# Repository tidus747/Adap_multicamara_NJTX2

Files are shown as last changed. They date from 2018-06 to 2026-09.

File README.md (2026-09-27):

# NVIDIA Jetson TX2 Multi-Camera System

Multidisciplinary engineering project covering mechanical design, custom electronics, embedded Linux integration, camera-array calibration and disparity estimation.

> Master's Degree Final Project in Industrial Engineering
>
> Author: Iván Rodríguez-Méndez
>
> Supervisor: Fernando Luis Rosa González
>
> Universidad de La Laguna, 2018





## Project overview

The goal of this project was to develop the hardware and software required to operate a multi-camera array around the NVIDIA Jetson TX2.

The work covered the complete engineering chain:

- custom electronic modules
- mechanical design and fabrication
- camera positioning and physical calibration
- Linux kernel and Device Tree configuration
- camera sensor integration
- GStreamer capture workflows
- multi-camera calibration
- disparity estimation

The repository contains the original engineering artifacts, experimental captures and the complete Master's thesis.

## System architecture

```mermaid
flowchart LR
    SCENE[Scene] --> CAM[Camera sensors]
    CAM --> ELEC[Custom camera and bridge electronics]
    ELEC --> JETSON[NVIDIA Jetson TX2]

    MECH[Mechanical camera array] --> CAM
    ADJ[Camera angle adjustment] --> MECH

    JETSON --> KERNEL[Kernel and Device Tree]
    KERNEL --> DRIVER[Camera drivers]
    DRIVER --> GST[GStreamer capture]

    GST --> DATA[Multi-camera datasets]
    DATA --> CAL[Array calibration]
    CAL --> DISP[Disparity estimation]
    DISP --> RESULTS[Experimental results]
```

See [docs/system-architecture.md](docs/system-architecture.md) for the detailed system view.

## Engineering scope

### Mechanical design

The mechanical subsystem includes:

- complete camera array structure
- camera support and positioning
- camera-angle adjustment mechanisms
- physical calibration elements
- FreeCAD design files
- 3D-printing and manufacturing resources

Source material: [Desarrollo_Mecanico](Desarrollo_Mecanico)

### Electronic design

The electronic development includes several prototype and production-oriented modules:

- OV5680 camera modules
- camera bridge modules
- Raspberry Pi camera sensor adapters
- debug modules
- CNC fabrication test boards
- Jetson support hardware

Source material: [Desarrollo_Electronico](Desarrollo_Electronico)

### Embedded software

The Jetson TX2 integration required work below the application layer.

The repository includes:

- Jetson TX2 Device Tree resources
- Device Tree modifications
- IMX219 sensor support
- camera driver modifications
- kernel compilation scripts
- GStreamer RAW10 patches
- Auvidea J20 configuration
- GPIO setup utilities
- camera-array control and calibration scripts

Source material: [Desarrollo_Software](Desarrollo_Software)

### Computer vision and validation

The completed system was used to acquire multi-camera image sets and validate the full integration through calibration and disparity-estimation experiments.

Experimental data: [Array_captures](Array_captures)

## Engineering case study

A condensed explanation of the problem, system integration and validation strategy is available in:

[docs/engineering-case-study.md](docs/engineering-case-study.md)

The original Master's thesis is preserved in:

[Documentos/tfm_ivan_comp.pdf](Documentos/tfm_ivan_comp.pdf)

## Developed system

<p align="center">
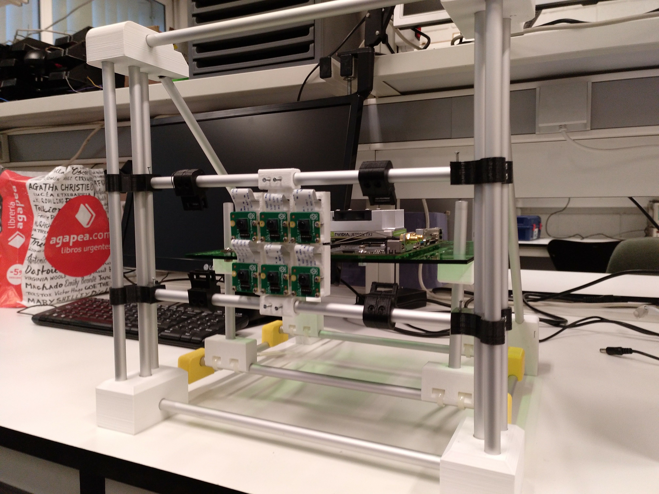
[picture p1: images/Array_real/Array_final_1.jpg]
  
</p>

<p align="center">
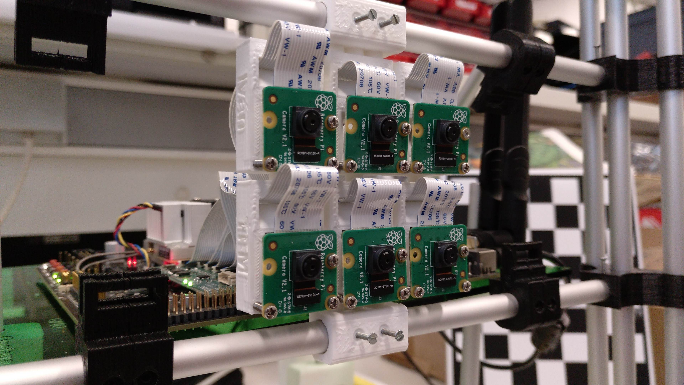
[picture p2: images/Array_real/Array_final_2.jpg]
  
</p>

## Mechanical design

<p align="center">
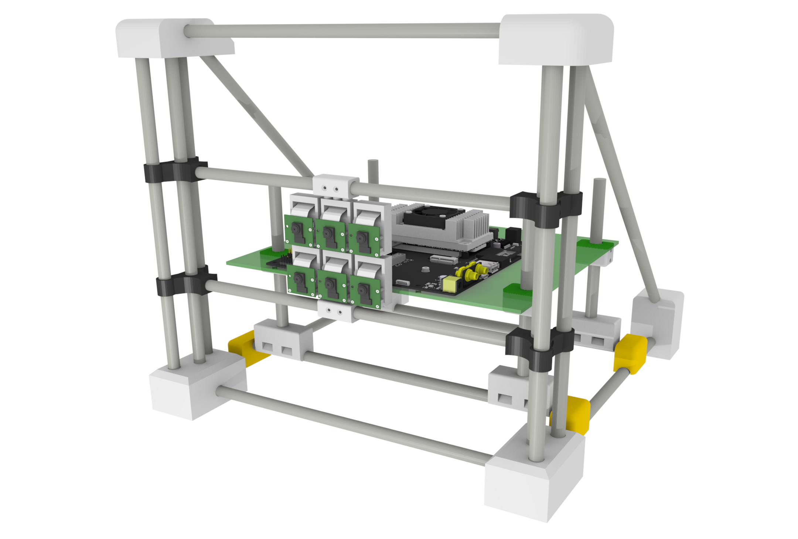
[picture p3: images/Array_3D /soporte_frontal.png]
  
</p>

<p align="center">
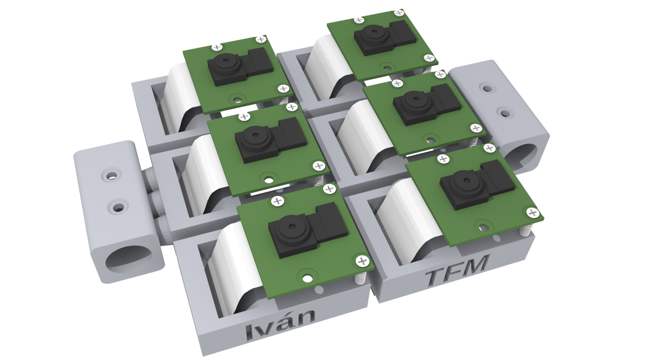
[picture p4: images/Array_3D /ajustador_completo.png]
  
</p>

## Experimental results

Representative disparity-estimation results obtained with the camera array:

<p align="center">
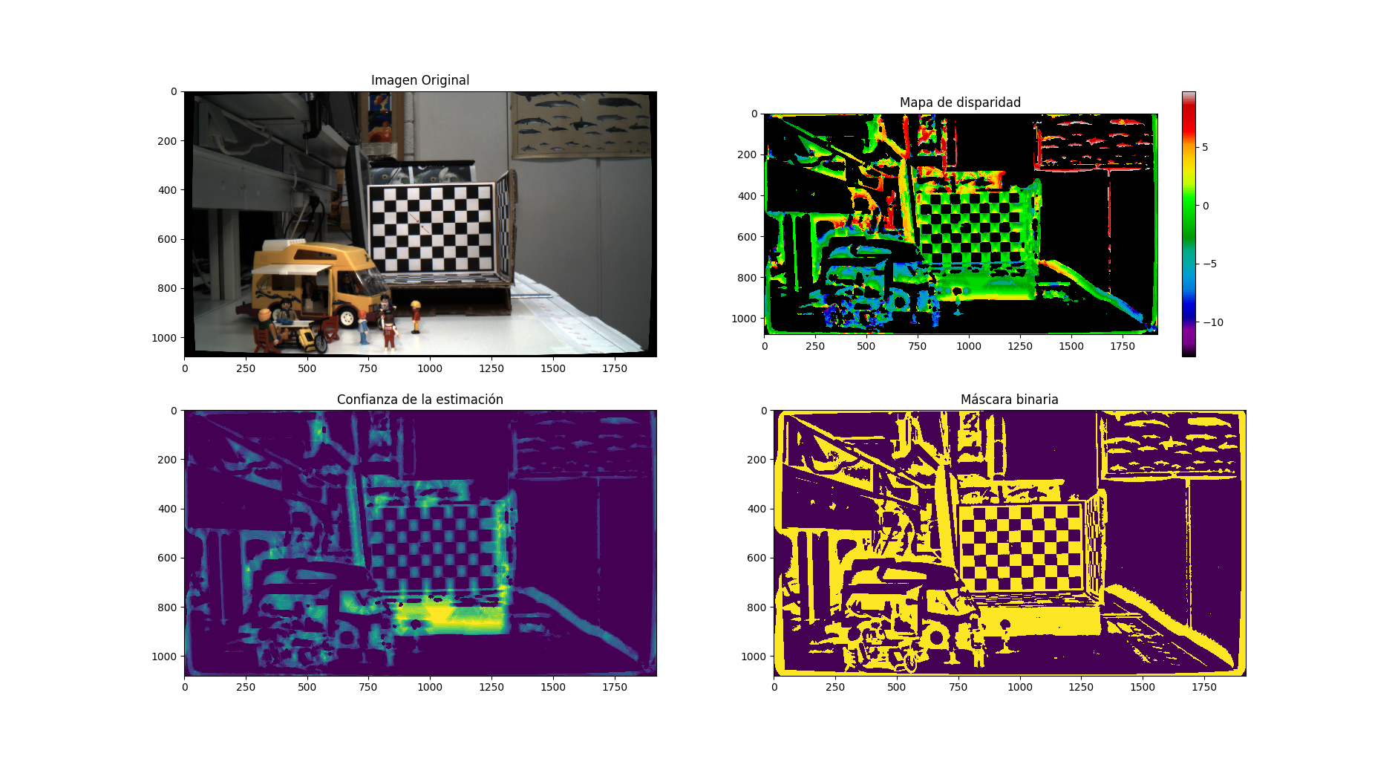
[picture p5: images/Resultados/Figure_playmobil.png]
  
</p>

<p align="center">
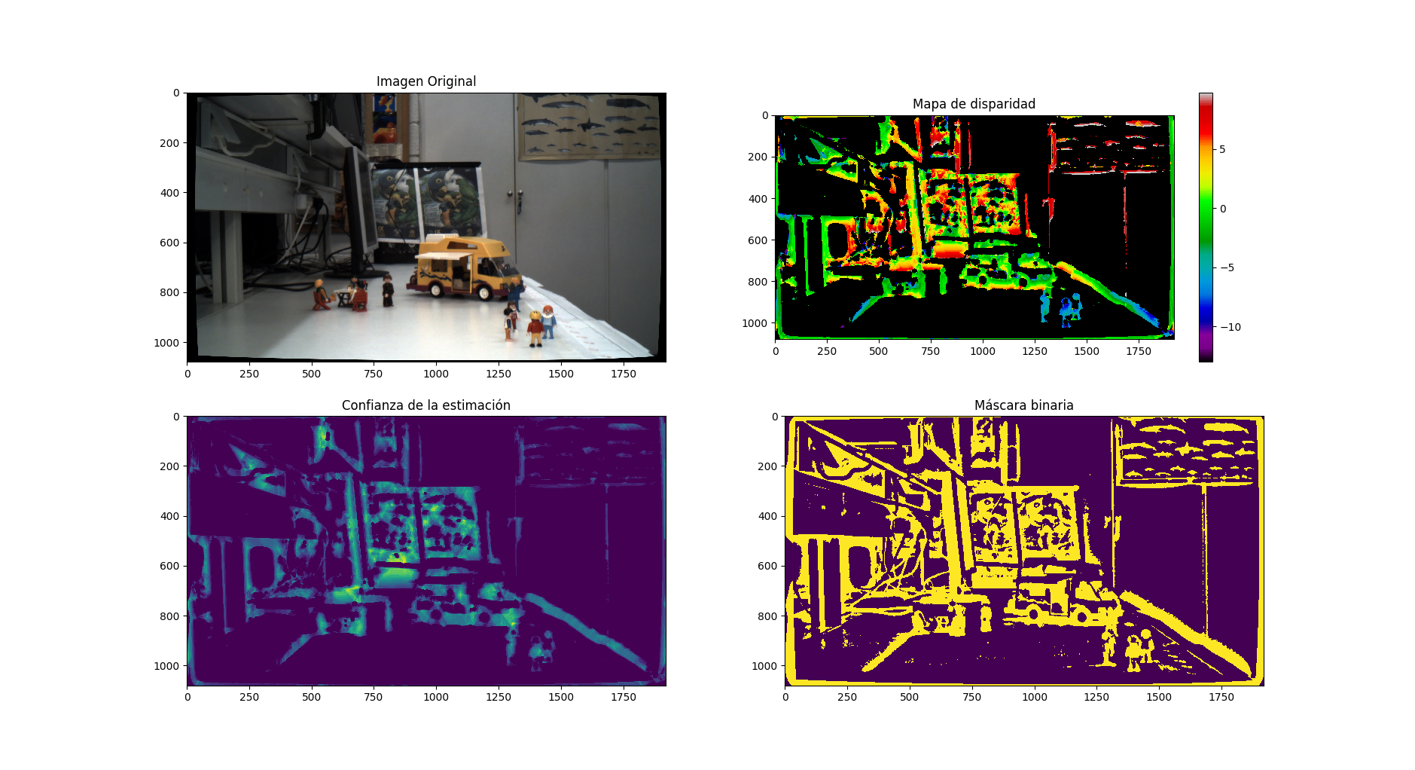
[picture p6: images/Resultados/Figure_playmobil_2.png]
  
</p>

<p align="center">
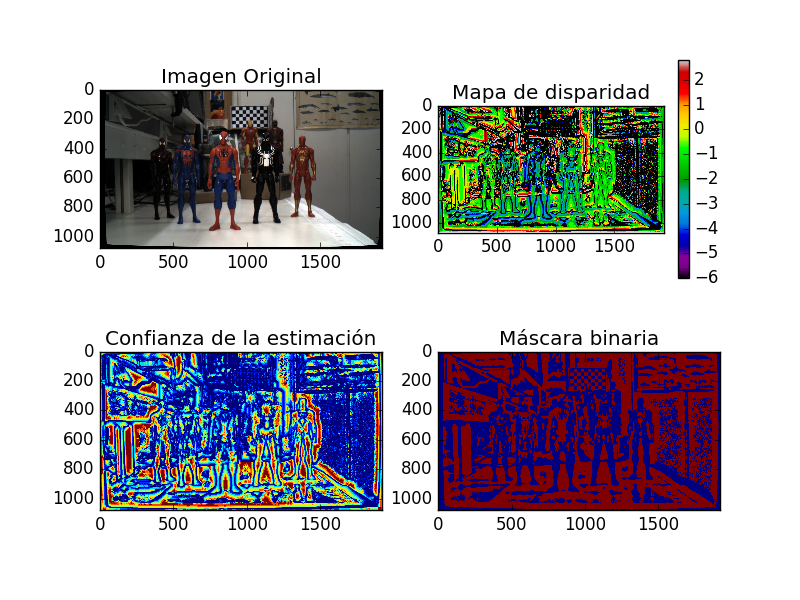
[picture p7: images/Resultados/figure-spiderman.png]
  
</p>

## Repository map

```text
Adap_multicamara_NJTX2/
|-- Array_captures/
|   `-- Experimental multi-camera datasets
|-- Desarrollo_Electronico/
|   `-- Electronic design and fabrication files
|-- Desarrollo_Mecanico/
|   `-- Mechanical design and fabrication files
|-- Desarrollo_Software/
|   `-- Jetson, kernel, drivers, GStreamer and camera scripts
|-- Documentos/
|   `-- Original Master's thesis
|-- docs/
|   |-- engineering-case-study.md
|   `-- system-architecture.md
|-- images/
|   |-- Array_3D /
|   |-- Array_real/
|   |-- Modelo3D_Placas/
|   `-- Resultados/
|-- CONTRIBUTING.md
|-- LICENSE
`-- README.md
```

## Why this project matters

This project is fundamentally an integration project.

The camera system only works when multiple engineering domains work together:

```mermaid
flowchart TD
    SYS[Working multi-camera system]
    ME[Mechanical alignment] --> SYS
    EE[Electronic interfaces] --> SYS
    EMB[Embedded Linux integration] --> SYS
    IMG[Image acquisition] --> SYS
    CAL[Calibration] --> SYS
    CV[Computer vision] --> SYS
```

It required moving repeatedly between physical design, electronics, low-level software, system bring-up and experimental validation.

## Historical note

This project was developed in 2018 using the NVIDIA Jetson TX2 platform and the JetPack/kernel ecosystem available at that time.

The repository is preserved as an engineering record. Kernel patches, Device Tree files, drivers and software instructions should therefore be treated as historical technical material rather than current Jetson setup instructions.

## Development workflow

The original project history is preserved. Future maintenance uses GitFlow without rewriting historical engineering artifacts.

See [CONTRIBUTING.md](CONTRIBUTING.md).

## License

Released under the GNU General Public License v3.0. See [LICENSE](LICENSE).

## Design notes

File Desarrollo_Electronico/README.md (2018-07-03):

# Contenido del directorio

En este directorio se pueden encontrar los diseños de los siguientes módulos:

- [Módulo de cámara para el sensor OV5680](https://github.com/tidus747/Adap_multicamara_NJTX2/tree/master/Desarrollo_Electronico/Modulo_Camara) - Diseño para el módulo de cámara con sensor OV5680.
- [Módulo de cámara para el sensor OV5680 con pistas grandes](https://github.com/tidus747/Adap_multicamara_NJTX2/tree/master/Desarrollo_Electronico/Modulo_Camara_pistas_grandes) - Modificación con pistas más anchas para el módulo de cámara con sensor OV5680.
- [Módulo de depuración](https://github.com/tidus747/Adap_multicamara_NJTX2/tree/master/Desarrollo_Electronico/Modulo_Depuracion) - Diseño para el módulo de depuración de líneas de la Nvidia Jetson TX2.
- [Módulo para pruebas de CNC](https://github.com/tidus747/Adap_multicamara_NJTX2/tree/master/Desarrollo_Electronico/Modulo_pruebas_CNC) - Diseño para el módulo de pruebas de CNC.
- [Módulo para pruebas de CNC versión Tiny](https://github.com/tidus747/Adap_multicamara_NJTX2/tree/master/Desarrollo_Electronico/Modulo_pruebas_CNC_Tiny) - Diseño reducido para el módulo de pruebas de CNC.
- [Módulo puente para módulo de cámara basado en el sensor OV5680](https://github.com/tidus747/Adap_multicamara_NJTX2/tree/master/Desarrollo_Electronico/Modulo_puente) -  Diseño del módulo puente para el módulo de cámara basado en el sensor OV5680.
- [Módulo puente para módulo de cámara basado en el sensor OV5680 con VIAS MOD](https://github.com/tidus747/Adap_multicamara_NJTX2/tree/master/Desarrollo_Electronico/Modulo_puente_VIAS_MOD) - Diseño del módulo puente para el módulo de cámara basado en el sensor OV5680 con VIAS más grandes.
- [Módulo puente para módulo de cámara basado en el sensor OV5647/IMX219](https://github.com/tidus747/Adap_multicamara_NJTX2/tree/master/Desarrollo_Electronico/Modulo_puente_Raspberry_Camera) - Diseño para el módulo puente para los módulos de cámara con sensor OV5647/IMX219.
- [Módulo puente para módulo de cámara basado en el sensor OV5647/IMX219 sin EEPROM](https://github.com/tidus747/Adap_multicamara_NJTX2/tree/master/Desarrollo_Electronico/Modulo_puente_Raspberry_Camera_Dupont_NO_EEPROM) - Diseño para el módulo puente para los módulos de cámara con sensor OV5647/IMX219 sin EEPROM.
- [Diseño para el soporte de la Nvidia Jetson TX2](https://github.com/tidus747/Adap_multicamara_NJTX2/tree/master/Desarrollo_Electronico/Soporte_Jetson) - Diseño para el soporte de la Nvidia Jetson TX2.

# Módulos desarrolados

<p align="center">
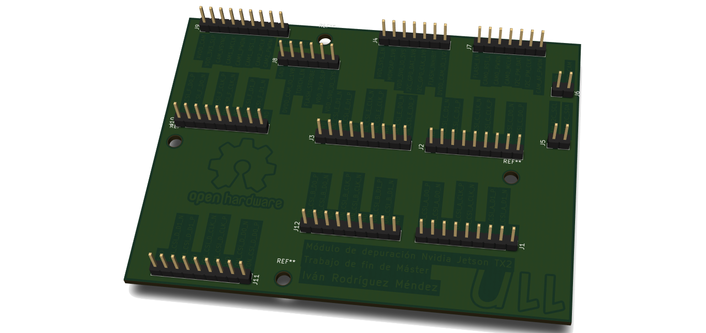
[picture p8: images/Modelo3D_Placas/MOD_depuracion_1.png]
  
</p>

<p align="center">
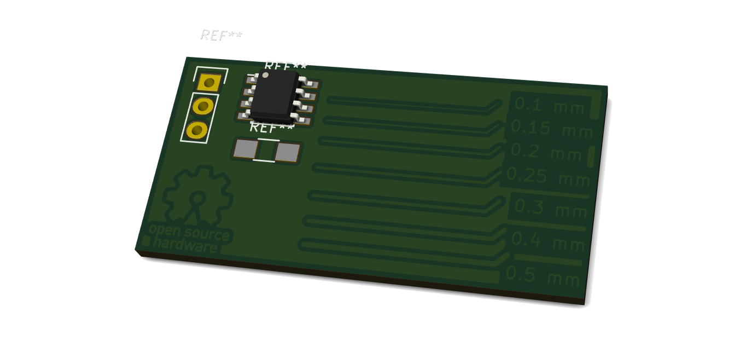
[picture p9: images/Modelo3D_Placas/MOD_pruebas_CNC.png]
  
</p>

<p align="center">
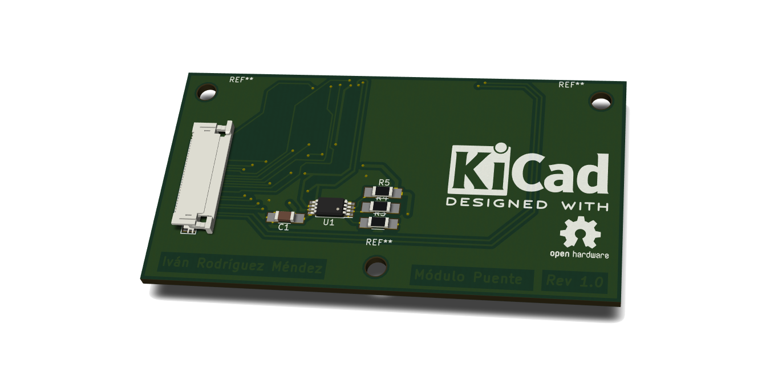
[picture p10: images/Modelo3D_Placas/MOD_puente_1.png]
  
</p>

<p align="center">
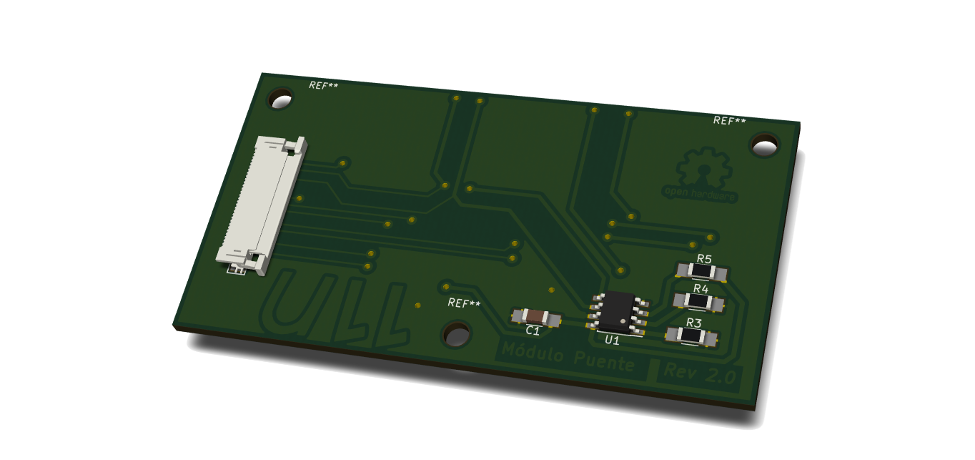
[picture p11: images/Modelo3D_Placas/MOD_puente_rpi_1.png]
  
</p>

<p align="center">
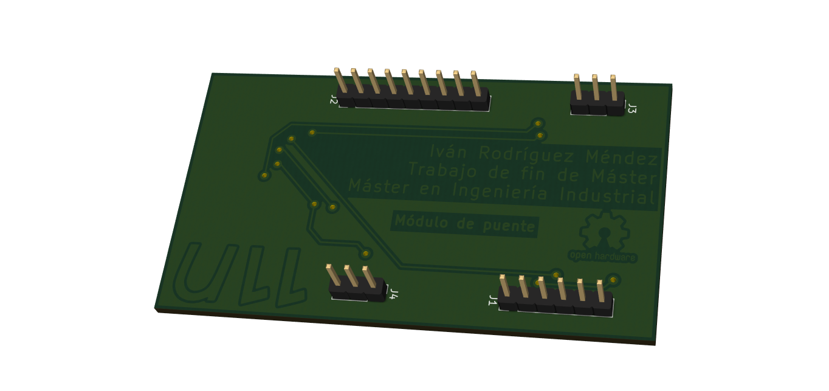
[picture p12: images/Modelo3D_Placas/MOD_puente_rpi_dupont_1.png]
  
</p>

<p align="center">
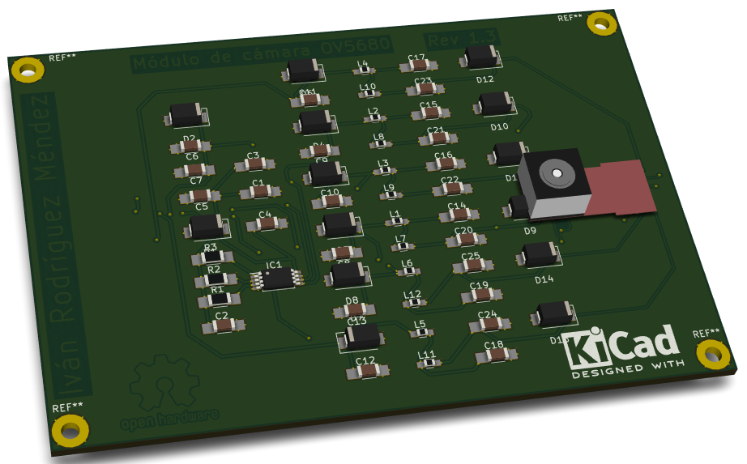
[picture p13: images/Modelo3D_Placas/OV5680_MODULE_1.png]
  
</p>

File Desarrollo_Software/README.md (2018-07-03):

# Contenido del directorio

En este directorio pueden encontrarse los siguientes los siguientes desarrollos realizados y recursos:

- [*Scripts* Array de cámaras](https://github.com/tidus747/Adap_multicamara_NJTX2/tree/master/Desarrollo_Software/Camera_array) - *Scripts* para el control y la calibración del *array* de cámaras.
- [*Device Tree Binary* Originales de la NJTX2](https://github.com/tidus747/Adap_multicamara_NJTX2/tree/master/Desarrollo_Software/Jetson_TX2_original_DTB) - Ficheros originales para los *Device Tree Binary* de la Nvidia Jetson TX2 en su versión del *Jetpack 28.2*.
- [Código fuente módulos de cámara PDF](https://github.com/tidus747/Adap_multicamara_NJTX2/tree/master/Desarrollo_Software/PDF_Code_Cameras) - PDFs con los códigos fuente de los módulos de cámara utilizados.
- [Parches para el *device tree* para el sensor IMX219](https://github.com/tidus747/Adap_multicamara_NJTX2/tree/master/Desarrollo_Software/Patches_DT_IMX219) - Parches para el *device tree* para permitir la utilización de un módulo de cámara con el sensor IMX219.
- [Parches para *GStreamer*](https://github.com/tidus747/Adap_multicamara_NJTX2/tree/master/Desarrollo_Software/Patches_Gstreamer_RAW10) - *Scripts* para aplicar los parches de *Gstreamer* en la Nvidia Jetson TX2. Estos parches permiten el uso de capturas de imágenes *raw* de 10 bits.
- [Parches para el uso de sensores de Raspberry Pi](https://github.com/tidus747/Adap_multicamara_NJTX2/tree/master/Desarrollo_Software/Patches_IMX219) - *Scripts* para el uso de sensores de Raspberry Pi en la Nvidia Jetson TX2.
- [*Scripts* para la compilación del *Kernel* de la NJTX2](https://github.com/tidus747/Adap_multicamara_NJTX2/tree/master/Desarrollo_Software/Scripts_Jetson) - *Scripts* para la compilación del *kernel* de la Nvidia Jetson TX2.
- [*Scripts* para la configuración del Auvidia J20](https://github.com/tidus747/Adap_multicamara_NJTX2/tree/master/Desarrollo_Software/Setup_Auvidea_J20) - *Scripts* para la configuración del Auvidea J20 y los GPIO.

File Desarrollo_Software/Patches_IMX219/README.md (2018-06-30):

# Conexión de la cámara de Raspberry Pi (Sensor IMX219, V2.1) con Nvidia Jetson TX2

## Introducción

En esta guía explicaremos todos los pasos seguidos para la correcta generación de los ficheros necesarios en la conexión del **sensor IMX219**. Para este propósito en primer lugar, definiremos los pasos a seguir en el desarrollo para la implementación de los módulos de cámra. Todos los recursos que hemos utilizado para el desarrollo de esta guía, se encuentran al final de la misma.

## Preparación de elementos necesarios (Hardware/Software)

Antes de comenzar con el desarrollo es necesario contar con una serie de elementos básicos tanto de software como de hardware. Comenzaremos con los elementos de hardware necesarios y continuaremos enumerando los elementos de software.

### Hardware

Lo primero que necesitaremos será el kit de desarrollo de [Nvidia Jetson TX2](https://www.nvidia.es/autonomous-machines/embedded-systems-dev-kits-modules/). Por otro lado, necesitaremos un dispositivo que nos permita conectar las cámaras a la Jetson TX2, en nuestro caso hemos optado por el conector [J20 de Auvidea](https://auvidea.com/j20/). Por último, necesitaremos los módulos de cámara que implementaremos en nuestra placa. En este caso tenemos dos opciones si hablamos de módulos compatibles con Raspberry Pi. Podemos optar por la [versión 2.1](https://www.raspberrypi.org/products/camera-module-v2/) o por la [versión 1.3](https://uk.pi-supply.com/products/raspberry-pi-camera-board-v1-3-5mp-1080p). Optaremos por implementar la versión más actualizada de este sensor, esta es la versión 2.1.

- Sensor OV5647 (Versión 1.3 de cámara Rpi)

<p align="center">
  
</p>
     
- Sensor IMX219 (Version 2.1 de cámara Rpi)

<p align="center">
  
</p>

### Software

Con respecto al software necesario para la implementación de esta herramienta, necesitaremos lo siguiente:

- [Ubuntu 16.04 LTS](http://releases.ubuntu.com/16.04/), para la programación y la carga del nuevo kernel en la NVDIA Jetson (tanto para la TX1 como para la TX2) es necesario contar con este sistema operativo. Esto es así debido a que el SDK desarrollado por NVIDIA para la carga del código está especificamente desarrollado para este sistema.
- [SDK Jetson TX1/TX2](https://developer.nvidia.com/embedded/jetpack), el NVIDIA Jetpack nos proporciona las herramientas necesarias para la descarga y la modificación del código fuente de las NVIDIA Jetson. Por otro lado, también instalará en nuestro sistema herramientas como TensorFlow o ejemplos para la renderización con CUDA que posteriormente podrías ser implementados en el kit de desarrollo.
- [Linaro ToolChain](http://releases.linaro.org/components/toolchain/binaries/5.3-2016.02/), esta herramienta nos servirá para compilar el kernel de la NVIDIA Jetson en nuestro sistema y posteriormente cargarlo en la placa.

## Implementación del sensor a nivel de Software

Antes de comenzar, debemos determinar cuales son los pasos que debemos ejecutar para la correcta implementación del código en la plataforma:

1. Preparar los ficheros fuente del *Device Tree*
2. Modificar los archivos del *Device Tree* correctamente.
3. Modificar los ficheros fuente del módulo de cámara. 
4. Configurar el Kernel para detectar los módulos qe hemos añadido.
5. Compilar el kernel.
6. Cargar el kernel en la NVIDIA Jetson TX2.
7. Cargar los **DTB** en la Jetson TX2.
8. Testear el correcto funcionamiento del sistema.

Una vez hemos definido los pasos a seguir, podemos introducir cada uno de ellos con un mayor nivel de detalle.

### Preparación de ficheros fuente del *Device Tree* 

En general, en los sistemas Linux, existen dos formas de modificar el kernel. Los dos métodos son los siguientes:

- Mediante el **Archivo de configuración del kernel**: esto le indicará al kernel qué características y controladores deberían compilarse. También puede especificar qué controladores deben empaquetarse en el kernel y cuáles deben compilarse pero separarse del kernel. En nuestro caso, modificaremos esto para decirle al kernel que cree compatibilidad con el controlador IMX219.

- Mediante el **Device Tree Source (DTS)**: así es como puede configurar el núcleo en el arranque para que se comporte de manera diferente en una placa frente a otra. Un claro ejemplo lo podmeos encontrar con la Raspberry Pi y la Raspberry Pi Zero. Estas dos placas son muy diferentes a simple vista pero tienen el mismo kernel porque hay dos archivos DTS diferentes para él.

Como hemos comentado, necesitamos agregar soporte para la cámara IMX219 (Cámara Raspberry Pi Modelo 2.1). Debido a que no existe un mecanismo para reconocer las cámaras CSI mientras el kernel se está ejecutando, tenemos que modificar el **DTS** para decirle al kernel cómo reconocerlas. Esto es muy diferente con respecto al funcionamiento de un USB, por ejemplo, porque en el caso del USB existe un mecanismo estándar que el kernel puede usar para reconocer cuando se inserta un nuevo dispositivo, para el CSI esto no es así. Por lo tanto, cada placa está configurada con un archivo interno conocido como **DTB (Device Tree Binary)**. Este **DTB** es una versión compilada de los archivos **DTS (Device Tree Source)** y **DTSi (Device Tree Source Include)**.

Necesitamos configurar el archivo DTS para reconocer la cámara IMX219, para hacer esto tenemos que describir lo siguiente:

- A qué puertos CSI están conectadas las cámaras.
- Cómo se deben configurar las cámaras usando I2C.
- Qué modos de visualización tienen las cámaras (¿Tiene 1920x1080 y / o 1280x720).
- Cómo configurar la arquitectura de entrada de video del TX2.

Todo esto debe recogerse en un fichero **DTS**. Podemos este fichero desde cero, pero para la gran mayoría de casos puede usarse el archivo **DTS** predeterminado utilizado para los kits de desarollo de NVIDIA. En el caso de que se quiera obtener un mayor control sobre este procedimiento puede consultarse el siguiente [enlace](https://cospandesign.github.io/linux/2017/10/27/tx2-bringup.html). En nuestro caso, optaremos por crear nuestro fichero **DTS** partiendo de los códigos creados por NVIDIA. La ruta predefinida para localizar el fichero de configuración predeterminado en la Jetson TX2 es:

```
Linux_for_Tegra/sources/hardware/nvidia/platform/t18x/quill/kernel-dts/tegra186-quill-p3310-1000-c03-00-base.dts
```
En la ruta anterior podemos encontrar algo de información aunque realmente, gran parte de la configuración se encuentra en esta otra ruta:

```
Linux_for_Tegra/sources/hardware/nvidia/platform/t18x/quill/kernel-dts/tegra186-quill-p3310-1000-a00-00-base.dts
```

Antes de continuar, es probable que aún no dispongas de los ficheros que hemos mencionado por lo que será necesario descargarlos. En la siguiente sección explicaremos como realizar este proceso correctamente.

### Descarga del NVIDIA JetPack 3.2 y los ficheros fuente del kernel

#### Descarga del NVIDIA JetPack

1. Descarga la versión 3.2 (o su versión más reciente) desde el siguiente [enlace](https://developer.nvidia.com/embedded/dlc/jetpack-l4t-3_2-ga).
2. Mueve los archivos binarios que acabas de descargar a un directorio donde quieras que ocurra la instalación. La ruta recomendada sería `/home/$USER/JetPack-L4T-3.2`. En tal caso, los comandos a introducir en el terminal serían los siguientes:

```
mkdir -p /home/$USER/JetPack-L4T-3.2
mv JetPack-L4T-3.2-linux-x64_b196.run /home/$USER/JetPack-L4T-3.2/
```

3. Marcamos como ejecutable el archivos y le asignamos los permisos.

```
cd /home/$USER/JetPack-L4T-3.2
chmod +x JetPack-L4T-3.2-linux-x64_b196.run
```

4. Instalar el JetPack.

```
./JetPack-L4T-3.2-linux-x64_b196.run
```

5. Sigue las instrucciones para la instalación. Selecciona la placa en el instalador (TX1, TX2, TX2i).

#### Descarga de los ficheros fuente del kernel

Para descargar todos los ficheros necesarios llamaremos `$DEVDIR` al directorio donde se encuentran los ficheros de desarrollo. En el caso de haber usado los comandos indtroducidos anteriormente tendríamos: 

- **Para la TX1**
```
export DEVDIR=$HOME/JetPack-L4T-3.2/64_TX1/Linux_for_Tegra
```
- **Para la TX2**
```
export DEVDIR=$HOME/JetPack-L4T-3.2/64_TX2/Linux_for_Tegra
```

Para descargar todos los ficheros fuente, usaremos el script *source_sync.sh* 

```
cd $DEVDIR/
./source_sync.sh
```

Este comando descargará además el bootloader y el kernel. Cuando el script pregunte por el tag que queremos sincronizar, introducir **tegra-l4t-r28.2** en ambos casos.

### Modificación de ficheros fuente del *Device Tree* 

Una vez hemos descargado los ficheros fuente, modificaremos el fichero disponible en la siguiente ruta:

```
Linux_for_Tegra/sources/hardware/nvidia/platform/t18x/quill/kernel-dts/tegra186-quill-p3310-1000-a00-00-base.dts
```

Para simplificar el desarrollo, se desactivará el soporte inteligente para la administración de cámaras de NVIDIA y se eliminarán las referencias a otros módulos de cámara. El fichero tendría el siguiente aspecto:

```
#include <t18x-common-platforms/tegra186-quill-common-p3310-1000-a00.dtsi>
#include <t18x-common-platforms/tegra186-quill-power-tree-p3310-1000-a00-00.dtsi>
//#include <t18x-common-platforms/tegra186-quill-camera-modules.dtsi>
#include <t18x-common-modules/tegra186-display-e3320-1000-a00.dtsi>

/* comms dtsi file should be included after gpio dtsi file */
#include <t18x-common-platforms/tegra186-quill-comms.dtsi>
#include <t18x-common-plugin-manager/tegra186-quill-p3310-1000-a00-plugin-manager.dtsi>
#include <t18x-common-modules/tegra186-super-module-e2614-p2597-1000-a00.dtsi>
#include <t18x-common-plugin-manager/tegra186-quill-display-plugin-manager.dtsi>
#include <t18x-common-prod/tegra186-priv-quill-p3310-1000-a00-prod.dtsi>
//#include <t18x-common-plugin-manager/tegra186-quill-camera-plugin-manager.dtsi>

#include <dt-bindings/linux/driver-info.h>
```

Ahora que hemos eliminado todas las referencias a las cámaras anteriores, vamos a agregar dos archivos. Uno que configurará la(s) cámara(s) de nivel de la placa y el otro para configurar la arquitectura interna de la Interfaz de video de la Jetson TX2.

Para ello, crearemos un nuevo archivo llamado *tegra186-my-camera-config-a00.dtsi* en el siguiente directorio:
```
Linux_for_Tegra/sources/hardware/nvidia/platform/t18x/common/kernel-dts/t18x-common-platforms/
```
Crearemos un segundo fichero con el mismo nombre en este otro directorio:
```
Linux_for_Tegra/sources/hardware/nvidia/platform/t18x/common/kernel-dts/t18x-common-modules/
```

El fichero *my-camera-config* se puede cambiar a lo que quieras y *a00* es solo la primera versión de este archivo.

Por el momento, usaremos la versión alojada en *platforms* del archivo como paso para el módulo, pero técnicamente se pueden anular los *modules* abstractos previstos para alguna plataforma general.

Dentro de la versión de *platforms* del archivo, incluimos la siguiente línea:
```
#include <t18x-common-modules/tegra186-my-camera-config-a00.dtsi>

```
Dentro del fichero de configuración necesitamos configurar una serie de parámetros para que la cámara sea capaz de funcionar. Los módulos son los siguientes:

* Permitir que los GPIOs de la Jetson TX2 puedan tener las siguientes funcionalidades:
    * Resetear las líneas
    * Posible incorporación de un multiplexor de direcciones I2C
* TX2’s host1x
    * Componente NVCSI: Este componente servirá para configurar las líneas CSI para comunicarse con las cámaras correctamente.
    * Componente VI: Configura la salida del NVCSI de forma directa a las líneas del ISP o directamente sobre la memoria del dispositivo.
    * Componente I2C: Configuración de la salida de la cámara a vídeo.
* GPIOs
    * Configurar los GPIOs para que posean cierto comportamiento como por ejemplo, resetear la cámara, encenderla o apagar sus reguladores.
* *Tegra-camera-platform*
    * Describir la localización física de la cámara.
    * Configurar el ISP para procesar las imágenes.
    * Describir otros elementos que puedan hacer falta a la cámara, como por ejemplo el enfoque.

Para comprender mejor todo lo anterior, se ha ilustrado la idea principal en la siguiente imagen:

<p align="center">
  
</p>

Todas las cámaras de Raspberry Pi tienen la misma dirección I2C, por lo que necesitamos una manera de distinguir una cámara de otra. La manera más fácil es con un multiplexor. Por esta razón, usaremos un multiplexor GPIO ya que el controlador para esta ya está integrado en el kernel.

En alto nivel si observamos la figura anterior, los datos de las cámaras de  Raspberry Pi llegan a la Jetson TX2 a través de los canales CSI representados en azul. Solo necesitamos un bus CSI de dos canales en este caso así que tomamos CSI A, si necesitáramos cuatro canales, reservaríamos dos bloques. El núcleo **NVCSI** extraerá la imagen sin formato del protocolo CSI y enviará los datos a **VI**. Este componente *Video Input* es esencialmente un enrutador de video, enruta el video al ISP o directamente a la memoria del dispositivo. Si la cámara de Raspberry Pi tiene un procesador de señal de imagen interno para convertir la imagen a una imagen RGB útil, le diremos al VI que enrute los datos de imagen a la memoria, pero como la cámara no tiene un ISP, usamos el ISP que posee la Jetson TX2. El proceso de enrutar los datos de video después del componente **VI** se realiza dentro del territorio del usuario cuando el kernel se inicia, por lo que terminamos una vez que el **VI** está conectado correctamente y el usuario ya tiene acceso a los datos.

Una vez comprendido todo esto, descargaremos los siguientes ficheros:

- [module tegra186-my-config-a00.dtsi](http://cospandesign.github.io/assets/files/posts/rpi-camera/tegra186-my-config-camera-a00_MODULE.dtsi)
- [platform tegra186-my-config-a00.dtsi](http://cospandesign.github.io/assets/files/posts/rpi-camera/tegra186-my-config-camera-a00_PLATFORM.dtsi)

Los directorios para guardar estos ficheros serían los siguientes:

```
Linux_for_Tegra/sources/hardware/nvidia/platform/t18x/common/kernel-dts/t18x-common-modules/
```
```
Linux_for_Tegra/sources/hardware/nvidia/platform/t18x/common/kernel-dts/t18x-common-platforms/
```
Por último, es necesario incluir el fichero `tegra186-my-camera-config-a00.dtsi` en la cabecera de nuestro fichero **dts** de configuración base del sistema. En el interior del fichero `tegra186-quill-p3310-1000-c03-00-base.dts` debemos añadir la siguiente línea:

```
#include <t18x-common-platforms/tegra186-my-camera-config-a00.dtsi>
```

Debería tener el siguiente aspecto:

```
#include "tegra186-quill-p3310-1000-a00-00-base.dts"
#include <t18x-common-platforms/tegra186-my-camera-config-a00.dtsi>

/ {
  nvidia,dtsfilename = __FILE__;
  nvidia,dtbbuildtime = __DATE__, __TIME__;
  ...
```

Una vez hecho esto podemos pasar a realizar las modificaciones sobre los módulos de cámara.

### Modificación de ficheros fuente del módulo de cámara

Lamentablemente, el controlador para el sensor **IMX219** suministrado por NVIDIA no es compatible con el módulo de Raspberry Pi. Por lo tanto, es necesario realizar algunas pequeñas modificaciones. Entre otras cosas, los requisitos del regulador deben eliminarse y las tablas de modos deben modificarse. Para realizar dicha modificación simplemente descargue los siguientes archivos:

- [imx219.c](http://cospandesign.github.io/assets/files/posts/rpi-camera/imx219.c)
- [imx219_mode_tbls.h](http://cospandesign.github.io/assets/files/posts/rpi-camera/imx219_mode_tbls.h)

Sobrescribe los ficheros existentes en el siguiente directorio con los descargados anteriormente:

```
Linux_for_Tegra/sources/kernel/kernel-4.4/drivers/media/i2c
```

### Configuración del kernel para detectar los módulos añadidos

Una vez descargado e instalado [toolchain](http://developer.ridgerun.com/wiki/index.php?title=Compiling_Tegra_X1/X2_source_code#Toolchain) podremos preparar el Kernel para su compilación. Durante la preparación, configuraremos los archivos que queremos compilar y entre ellos añadiremos los ficheros que hemos modificado y los módulos que necesitamos para el correcto funcionamiento de las cámaras.

EL primer paso será configurar el entorno que vamos a utilizar, introduciendo los comandos siguientes:

```
mkdir -p $DEVDIR/images/modules 
mkdir -p $DEVDIR/images/packages 
export CROSS_COMPILE=/opt/linaro/gcc-linaro-5.3-2016.02-x86_64_aarch64-linux-gnu/bin/aarch64-linux-gnu-
export CROSS32CC=/opt/linaro/gcc-linaro-5.3-2016.02-x86_64_arm-linux-gnueabihf/bin/arm-linux-gnueabihf-gcc
export KERNEL_MODULES_OUT=$DEVDIR/images/modules
export TEGRA_KERNEL_OUT=$DEVDIR/images
export ARCH=arm64
```

Limpiamos la configuración anterior del kernel:

```
cd $DEVDIR/sources/kernel/kernel-4.4
make mrproper
```

Configuramos el kernel:

```
make O=$TEGRA_KERNEL_OUT tegra18_defconfig
make O=$TEGRA_KERNEL_OUT menuconfig
```

**IMPORTANTE**: Para ejecutar el paso anterior, es posible que necesites instalar los siguientes paquetes si obtienes algún error al ejecutarlo.

```
sudo apt-get install libncurses5 libncurses5-dev
```

Al ejecutar el comando `make O=$TEGRA_KERNEL_OUT menuconfig` nos aparecerá un menú en el que podremos configurar los módulos que queremos cargar para su compilación en el kernel. La ventana que nos aparecerá en nuestro terminal será igual a la que vemos en la siguiente imagen:

<p align="center">
  
</p>

Dentro de este menú debemos buscar un módulo llamado *i2c-gpio-mux*. Para ello pulsaremos `/` para abrir el buscador y posteriormente escribiremos `I2C_MUX_GPIO`, pulsamos **enter** y debería aparecer lo siguiente:

<p align="center">
  
</p>

Presiona la tecla *1* hasta que aparezca un nuevo menú y posteriormente la tecla *y* para que un * aparezca en la selección de la siguiente manera:

<p align="center">
  
</p>

Haremos lo mismo para buscar el módulo de cámara IMX219. Una vez hecho esto, usaremos las flechas de dirección para guardar la configuración. El archivo debe tener el nombre por defecto, es decir, `.config`. Configurado el Kernel podemos pasar a su compilación.

### Compilación del kernel y los DTB

Una vez realizados los pasos anteriores ya podemos compilar el kernel de nuestro sistema.

```
make O=$TEGRA_KERNEL_OUT zImage
make O=$TEGRA_KERNEL_OUT dtbs
make O=$TEGRA_KERNEL_OUT modules
make O=$TEGRA_KERNEL_OUT modules_install INSTALL_MOD_PATH=$KERNEL_MODULES_OUT
```
Después de esto la imagen del kernel que hemos compilado se encontraría en la siguiente ruta:

```
$DEVDIR/images/arch/arm64/boot/Image
```

Y el *devicetree* se encontraría en:
```
$DEVDIR/images/arch/arm64/boot/dts/*.dtb
```

El siguiente paso sería crear un archivo que llamaremos *kernel_supplements.tbz2* y que contendrá los módulos del kernel que hemos compilado. Este archivo es uno de los requerimientos que tiene **Jetpack**.

```
cd $DEVDIR/images/modules/lib/modules/
ls .
```
Definiremos una variable con el mismo nombre que nos aparece al introducir el comando anterior:

```
export KERNEL_MODULES_NAME=4.4.38+
```
Reparamos los links simbólicos que se encuentran en el directorio de los módulos del kernel:

```
cd $DEVDIR/images/modules/lib/modules/$KERNEL_MODULES_NAME
rm build source
```

Creamos un *tarball*:

```
cd $DEVDIR/images/modules/
tar -cjf kernel_supplements.tbz2 *
mv kernel_supplements.tbz2 $DEVDIR/images/packages
```
Además de crear los módulos y la imagen del kernel, necesitamos volver a crear su archivo *kernel_headers.tbz2* (necesario para Jetpack). Por defecto, cuando se aplica algún parche al código del kernel y no se verifican sus cambios en el kernel, se agregará un sufijo -dirty a la versión de lanzamiento (compruebe `ls $DEVDIR/images/modules/lib/modules/` por ejemplo). Por esta razón específica necesitamos generar sus encabezados *tarball* de nuevo cambiando la versión de lanzamiento.

```
cd $DEVDIR/kernel
tar -xf kernel_headers.tbz2
```
Buscamos el nombre de la carpeta que contiene los *headers*, en nuestro caso es *linux-headers-4.4.38-tegra*:

```
ls | grep linux-headers
linux-headers-4.4.38-tegra
export KERNEL_HEADERS_NAME=linux-headers-4.4.38-tegra
```

Renombramos la carpeta:

```
mv $KERNEL_HEADERS_NAME linux-headers-$KERNEL_MODULES_NAME
tar -cjf kernel_headers_custom.tbz2 linux-headers-$KERNEL_MODULES_NAME
mv kernel_headers_custom.tbz2 $DEVDIR/images/packages
rm -rf linux-headers-$KERNEL_MODULES_NAME 
```

Creamos una copia de segurar de la imagen y los paquetes incluidos en el JetPack:

```
mkdir -p $DEVDIR/images/packages-backup
cp -rf $DEVDIR/kernel/* $DEVDIR/images/packages-backup
```

Copiamos el fichero DTB:
```
cp $DEVDIR/images/arch/arm64/boot/dts/tegra186-quill-p3310-1000-c03-00-base.dtb $DEVDIR/kernel/dtb
```
El paso final consiste en sobreescribir las imágenes por defecto con la imagen que hemos generado durante la compilación para instalarlas usando JetPack.

```
cd $DEVDIR/images
cp -rf arch/arm64/boot/Image arch/arm64/boot/zImage packages/kernel_supplements.tbz2 $DEVDIR/kernel/
cp -rf packages/kernel_headers_custom.tbz2 $DEVDIR/kernel/kernel_headers.tbz2
```

Ejecutamos el script *apply_binaries.sh* para generar la imagen que se va a cargar en la Jetson TX2.

```
cd $DEVDIR/
sudo ./apply_binaries.sh
```
### Carga del Kernel en la Nvidia Jetson TX2

1. Realizamos una copia de seguridad de nuestra imagen del sistema

```
cd $DEVDIR/bootloader/
mv system.img.raw system.img $DEVDIR/images/packages-backup/
```

2. Ejecutamos el Jetpack al igual que la primera vez que lo instalamos en nuestro sistema:

```
cd $DEVDIR/../../
JetPack-L4T-3.2-linux-x64_b196.run
```

JetPack se dará cuenta de que todo ya está construido e instalará sus nuevas imágenes en la Jetson TX2. Si tiene problemas para detectar la dirección IP espere unos 2 minutos y le dará la opción de ingresarla manualmente.

### Cargar los DTB en la Jetson TX2

En versiones anteriores de JetPack, actualizar el DTB era tan fácil como reemplazar el de la carpeta de arranque del directorio de inicio y también podía cambiar la entrada del FDT en `/boot/extlinux/extlinux.conf` para usar una diferente. Para **Jetpack 3.1** esto se modificó y se utiliza una partición separada para actualizar el archivo **DTB** y Nvidia dice que solo se puede actualizar mostrándolo de nuevo usando el script flash provisto.

```
$DEVDIR/images/arch/arm64/boot/dts/*.dtb
```
Remplazamos el DTB en `$DEVDIR/kernel/dtb``con el que hemos generado. Es recomendable hacer una copia de seguridad del DTB original.

```
cp $DEVDIR/images/arch/arm64/boot/dts/tegra186-quill-p3310-1000-c03-00-base.dtb $DEVDIR/kernel/dtb
```

Ponemos la placa en modo *recovery_USB* y cargamos la imagen:

```
cd $DEVDIR
sudo ./flash.sh -r -k kernel-dtb jetson-tx2 mmcblk1p1
```
**IMPORTANTE**: Usa mmcblk1p1 para una SDcard y mmcblk0p1 para emmc.

Existe otra forma de hacerlo directamente desde la placa, pero este método suele causar errores:
```
sudo dd if=tegra186-quill-p3310-1000-c03-00-base.dtb of=/dev/mmcblk0p13
```

### Test de funcionamiento

Después de que todo está construido y cargado en la Jetson. Deberían aparecer tener tres nuevas entradas `/dev/videoX`.

El siguiente comando puede utilizarse para capturar un video corto:

```
gst-launch-1.0 -v nvcamerasrc sensor-id=0 fpsRange="30 30" num-buffers=100 ! 'video/x-raw(memory:NVMM), width=(int)1920, height=(int)1080, format=(string)I420, framerate=(fraction)30/1' ! omxh264enc ! 'video/x-h264, width=(int)1920, height=(int)1080, format=(string)I420, framerate=(fraction)30/1' ! h264parse ! qtmux ! filesink location=test.mp4 -e
```

Como se está ejecutando a 30 FPS y captura 100 cuadros, el clip durará 2,33 segundos. Puede jugar con estos valores para modificarlo. También puede cambiar entre diferentes sensores con el valor **id del sensor**.

**NOTA**: Es posible que deba actualizar la memoria caché de configuración de imagen de su ISP para pedirle al kernel que reconstruya la configuración de ISP para su cámara específica. El caché está ubicado en:
```
/var/nvidia/nvcam/configuraciones
```
Borre todos estos archivos y reinicie el TX2 y deberían reconstruirse. Este valor depende de la configuración *tegra-camera-platform*.
## Recursos

A continuación vamos a listar los recursos que se han consultado para el desarrollo de esta guía en la que se pretende ilustrar todo el procedimiento seguido para la modificación del kernel, su compilación y su posterior implementación en la NVIDIA Jetson.

- [Raspberry Pi camera on TX2](http://cospandesign.github.io/linux,tx2,kernel,driver/2017/12/15/tx2-rpi-camera-port.html) - Guía para la conexión de tres módulos de Raspberry.
- [Desarrollo de un módulo de Kernel](http://cospandesign.github.io/linux,kernel,driver/2016/04/15/kernel-driver.html) - Guía básica para el desarrollo de un módulo de Kernel.
- [Porting NVIDIA TX2 to a new platform](https://cospandesign.github.io/linux/2017/10/27/tx2-bringup.html) - Portabilidad de código entre la Jetson TX2 y otras plataformas.
- [Guía de usuario para el desarrollo](https://developer.nvidia.com/embedded/dlc/l4t-documentation-28-1) - Guía para el desarrollo de código para la plataforma Jetson TX2.
- [Tópicos en el Foro de Nvidia](https://devtalk.nvidia.com/default/topic/1009359/jetson-tx2/jetson-tx1-sensor-driver-porting-to-tx2-4-4-kernel-/) - Hilo del foro de desarrolladores de NVIDIA donde se trata el desarrollo de módulos de cámara. 
- [Código fuente TX1](https://github.com/CospanDesign/nvidia-tx1-kernel) - Código fuente de la NVIDIA Jetson TX1.
- [Wiki sobre la compilación de Kernel TX1](http://developer.ridgerun.com/wiki/index.php?title=Compiling_Tegra_X1/X2_source_code#Build_Kernel) Guía para la compilación del kernel de la NVIDIA Jetson TX1.
- [Documentación sobre compilación de Kernel Linux](https://www.kernel.org/doc/Documentation/kbuild/modules.txt) - Web con documentación sobre la compilación del Kernel de Linux.
- [Wiki sobre la compilación de Kernel TX2](http://developer.ridgerun.com/wiki/index.php?title=Compiling_Tegra_X2_source_code) Guía para la compilación del kernel de la NVIDIA Jetson TX2.
- [Aplicación de parches en Kernel](https://www.kernel.org/doc/html/v4.11/process/applying-patches.html) Guía para la aplicación de parches en el Kernel de Linux.
- [Añadir sensor IMX219 a TX1](https://developer.ridgerun.com/wiki/index.php?title=Sony_IMX219_Linux_driver_for_Tegra_X1) Guía para añadir y compilar el código fuente del sensor OV5647 en la NVIDIA Jetson TX1.
- [Guía conector J20](http://developer.ridgerun.com/wiki/index.php?title=Getting_started_guide_for_Auvidea_J20_board) Wiki sobre el conector J20 desarrollado por Auvidea para la utilización de diferentes cámaras en la NVIDIA Jetson TX1/TX2.

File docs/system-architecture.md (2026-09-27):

# System Architecture

## Context

This project develops the hardware and software required to operate a multi-camera array around the NVIDIA Jetson TX2 platform.

The system combines mechanical design, custom electronics, embedded Linux configuration, image capture and computer vision processing.

## System view

```mermaid
flowchart LR
    SCENE[Scene] --> CAM[Camera sensors]
    CAM --> PCB[Camera and bridge electronics]
    PCB --> JETSON[NVIDIA Jetson TX2]

    MECH[Mechanical camera array] --> CAM
    ADJ[Camera angle adjustment] --> MECH

    JETSON --> DT[Kernel and Device Tree configuration]
    DT --> DRV[Camera drivers]
    DRV --> GST[GStreamer capture pipeline]

    GST --> RAW[Multi-camera image capture]
    RAW --> CAL[Camera array calibration]
    CAL --> DISP[Disparity estimation]
    DISP --> OUT[Depth-related results]
```

## Engineering domains

```mermaid
flowchart TD
    SYS[Multi-camera system]

    SYS --> ME[Mechanical]
    SYS --> EE[Electronics]
    SYS --> SW[Embedded software]
    SYS --> CV[Computer vision]

    ME --> ARRAY[Camera array structure]
    ME --> ANGLE[Camera angle adjustment]
    ME --> FAB[3D printed parts and drawings]

    EE --> MODULES[Camera and bridge modules]
    EE --> DEBUG[Debug hardware]
    EE --> FABPCB[PCB fabrication files]

    SW --> KERNEL[Kernel build scripts]
    SW --> DTS[Device Tree modifications]
    SW --> SENSOR[IMX219 support]
    SW --> GSTREAMER[GStreamer RAW10 patches]
    SW --> GPIO[Auvidea J20 GPIO setup]

    CV --> CAPTURE[Multi-camera capture]
    CV --> CALIBRATION[Software calibration]
    CV --> DISPARITY[Disparity maps]
```

## Mechanical subsystem

The mechanical design provides:

- the main camera array structure
- camera positioning and support
- adjustable camera angle mechanisms
- parts used during physical calibration
- manufacturing files and 3D-printing parameters

Relevant repository area:

`Desarrollo_Mecanico/`

## Electronics subsystem

The electronics work includes several iterations of camera, bridge, debugging and fabrication-oriented modules.

The repository contains design sources and manufacturing-related files for:

- OV5680 camera modules
- bridge modules
- Raspberry Pi camera sensor adaptation
- debug boards
- CNC fabrication tests
- Jetson support hardware

Relevant repository area:

`Desarrollo_Electronico/`

## Embedded software subsystem

The Jetson TX2 software work includes low-level platform adaptation required to operate the camera hardware.

The repository contains:

- original Jetson TX2 device tree resources
- Device Tree modifications
- IMX219 sensor driver modifications
- kernel compilation scripts
- GStreamer RAW10-related patches
- Auvidea J20 setup scripts
- GPIO configuration utilities

Relevant repository area:

`Desarrollo_Software/`

## Image-processing workflow

The project does not stop at camera bring-up. Captured images are used as the input to a computer-vision workflow.

```mermaid
flowchart LR
    C1[Camera 1] --> SET[Multi-camera capture]
    C2[Camera 2] --> SET
    C3[Camera 3] --> SET
    C4[Camera 4] --> SET
    C5[Camera 5] --> SET
    C6[Camera 6] --> SET

    SET --> CAL[Array calibration]
    CAL --> RECT[Geometric correspondence]
    RECT --> DISP[Disparity estimation]
    DISP --> RESULT[Experimental results]
```

Example capture sets are stored under `Array_captures/`, while representative outputs are available under `images/Resultados/`.

## Architecture significance

The main engineering challenge is the integration across domains.

Camera operation depends simultaneously on:

- mechanical alignment
- electrical compatibility
- sensor and carrier-board interfaces
- Linux kernel and Device Tree configuration
- image transport
- calibration quality
- image-processing algorithms

The project therefore represents a complete multidisciplinary engineering chain rather than an isolated software or hardware prototype.

## Historical platform note

This work was developed in 2018 around the NVIDIA Jetson TX2 ecosystem and the software stack available at that time.

Kernel, JetPack, driver and GStreamer details should be treated as historical technical material. They are valuable as implementation references, but they should not be assumed to apply directly to current Jetson platforms or software releases.

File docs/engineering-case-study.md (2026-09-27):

# Engineering Case Study

## Project

**Development of a multi-camera adaptation for NVIDIA Jetson TX2**

Master's Degree Final Project in Industrial Engineering, Universidad de La Laguna, 2018.

Author: **Iván Rodríguez-Méndez**

Supervisor: Fernando Luis Rosa González

## Problem

The project aimed to build the hardware and software infrastructure required to operate a multi-camera array using the NVIDIA Jetson TX2.

Doing this required more than connecting cameras to a development board. The work involved adapting interfaces, developing electronics and mechanics, configuring the embedded Linux camera stack, capturing synchronized image sets and validating the system through calibration and disparity-estimation experiments.

## Engineering scope

The project covered four tightly coupled areas:

- electronic design and fabrication
- mechanical design and fabrication
- embedded Linux and camera integration
- calibration and computer vision

## Solution approach

```mermaid
flowchart TD
    A[Define multi-camera concept] --> B[Design mechanical array]
    A --> C[Design camera electronics]

    B --> D[Fabricate and assemble structure]
    C --> E[Fabricate and validate electronics]

    D --> F[Integrate cameras]
    E --> F

    F --> G[Configure Jetson TX2]
    G --> H[Kernel and Device Tree work]
    H --> I[Camera capture pipeline]

    I --> J[Acquire multi-camera datasets]
    J --> K[Calibrate camera array]
    K --> L[Estimate disparity]
    L --> M[Evaluate results]
```

## Mechanical development

The mechanical subsystem includes the full array structure and camera-angle adjustment mechanisms.

The source files and manufacturing resources are stored in `Desarrollo_Mecanico/`.

The design was not only intended to hold the cameras. It also had to support repeatable positioning and physical calibration.

## Electronic development

Several custom electronic modules were designed during the project, including camera and bridge boards, debugging hardware and manufacturing experiments.

The design iterations and fabrication resources are stored in `Desarrollo_Electronico/`.

## Jetson TX2 integration

Camera bring-up required work below the application layer.

The software development includes:

- kernel compilation support
- Device Tree configuration
- sensor-driver modifications
- IMX219 integration
- Auvidea J20 configuration
- GPIO setup
- GStreamer modifications for image capture workflows

These resources are stored in `Desarrollo_Software/`.

## Validation

The completed system was used to acquire multi-camera image sets.

The repository contains:

- experimental capture datasets
- camera calibration files
- real system photographs
- disparity-estimation results

Representative results are stored in `images/Resultados/`.

## What this project demonstrates

From an engineering perspective, the project demonstrates:

- system-level integration across mechanics, electronics and software
- hardware/software interface debugging
- embedded Linux platform adaptation
- iterative prototyping and fabrication
- image-acquisition pipeline development
- calibration-driven validation
- computer-vision experimentation

## Project documentation

The original Master's thesis is preserved in:

`Documentos/tfm_ivan_comp.pdf`

The repository should be read as a historical engineering record of the system and its development process, rather than as a maintained modern Jetson software package.

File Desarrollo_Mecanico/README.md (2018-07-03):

# Contenido del directorio

En este directorio se pueden encontrar los diseños de los siguientes elementos mecánicos:

- [Ajustador de ángulo de cámaras](https://github.com/tidus747/Adap_multicamara_NJTX2/tree/master/Desarrollo_Mecanico/Ajuste_angulo_camaras) - Módulo mecánico para el ajustador de ángulo de cámaras.
- [Array completo](https://github.com/tidus747/Adap_multicamara_NJTX2/tree/master/Desarrollo_Mecanico/Array%20/Versi%C3%B3n%20V1.1) - Diseño mecánico para el *array* de cámaras completo.

Los parámetros de configuración de las impresoras 3D utilizados son:
- [Parámetros para las impresoras 3D](https://github.com/tidus747/Adap_multicamara_NJTX2/tree/master/Desarrollo_Mecanico/Parametros_Slic3r) - Fichero de configuración para el uso *Slic3r*.

Las plantillas para los planos utilizadas son:
- [Plantillas para los planos](https://github.com/tidus747/Adap_multicamara_NJTX2/tree/master/Desarrollo_Mecanico/Plantillas_Planos) - Plantillas para la elaboración de planos en *FreeCAD*.

# Diseño realizado

A continuación puede verse una imagen del *array* de cámaras desarrollado, además del ajustador de cámaras:

<p align="center">
  
</p>

<p align="center">
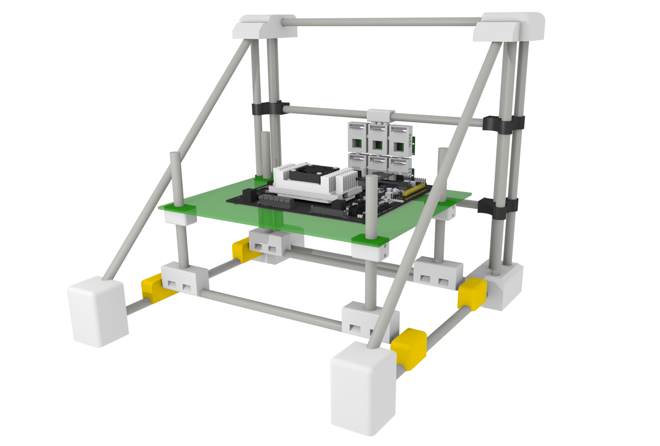
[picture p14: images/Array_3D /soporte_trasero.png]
  
</p>

<p align="center">
  
</p>

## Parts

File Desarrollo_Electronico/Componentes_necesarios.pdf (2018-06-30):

902 100 711 | es.rs-online.com | 902 100 611

RS Components
Avenida de Europa 19 - Edif. 3 28224 - Pozuelo de Alarcón Madrid

Su cesta de la compra en rsonline.es

Este pedido aún no se ha realizado pero se ha guardado automáticamente para su siguiente visita a rsonline.es

Descripción | Cantidad | Precio unitario

## Coste

Conector macho para PCB, Samtec serie
Q Strip QTH, Recto 120 pines 2 filas paso 0,5mm, Terminación Soldada
7678754
Samtec
QTH-060-01-L-D-A
Estado RoHS - Conforme

5

### 5 Disponible para entrega en

24/48 horas

10,46 €
Unidad

52,30 €

Resistencia de película gruesa TE Connectivity, 4,7kΩ, ±1%, 0,25W, 1.206, Serie CRG
1251191
TE Connectivity
CRG1206F4K7
Estado RoHS - Conforme

100
100 Disponible para entrega en 24/48 horas

0,006 €
unitario (En una
bolsa de 100)

0,60 €

Chip EEPROM AT24C02D-XHM-B Atmel, 2kbit, 256 x, 8bit Serie I2C, 1,7 → 3,6 V, 8 pines TSSOP
8988620
Atmel
AT24C02D-XHM-B
Estado RoHS - Conforme

25

### 25 Disponible para entrega

en 24/48 horas

0,28 €
unitario
(Suministrado en
múltiplos de 25)

7,00 €

Condensador cerámico multicapa MLCC, KEMET, 100nF, ±5%, 50V dc, Montaje en Superficie, X7R dieléctrico
6480761
KEMET
C1206C104J5RACTU
Estado RoHS - Conforme

20

### 20 Disponible para entrega

en 24/48 horas

0,134 €
unitario
(Suministrado en
múltiplos de 10)

2,68 €

Condensador cerámico multicapa MLCC, TDK, 4,7μF, ±10%, 25V dc, Montaje en Superficie, X7R dieléctrico
7407584
TDK
C3216X7R1E475K160AC
Estado RoHS - Conforme

50

### 50 Disponible para entrega

en 24/48 horas

0,247 €
unitario
(Suministrado en
múltiplos de 50)

12,35 €

Condensador cerámico multicapa MLCC, KEMET, 12pF, ±5%, 50V dc, Montaje en Superficie, C0G dieléctrico
8029986
KEMET
C1206C120J5GACTU
Estado RoHS - Conforme

500
500 Disponible para entrega en 24/48 horas

0,057 €
unitario
(Suministrado en
Carretes de 500)

28,50 €

ON Semiconductor 4.57 x 2.92 x 2.05mm Simple 2.05mm 4.57mm 1SMA5917BT3G +150 °C 1,5 W 2.5μA 5Ω -65 °C 7925335
ON Semiconductor
1SMA5917BT3G
Estado RoHS - Conforme

20

### 20 Disponible para entrega

en 24/48 horas

0,256 €
unitario
(Suministrado en
múltiplos de 20)

5,12 €

902 100 711 | es.rs-online.com | 902 100 611

Inductor de montaje superficial multicapa Murata, 18 nH, ±2%, Ferrita, 0603 (1608M), SRF: 2,3GHz, Q: 17, 100mA dc
7859196
Murata
LQP18MN18NG02D
Estado RoHS - Conforme

50

### 50 Disponible para entrega

en 24/48 horas

0,207 €
unitario (En una
bolsa de 10)

10,35 €

Conector FPC, Molex, Serie FFC/FPC SMT, 0,5mm, 1 fila, 30, Ángulo de 90°, Montaje Superficial, Hembra
6702557
Molex
54104-3031
Estado RoHS - Conforme

10

### 10 Disponible para entrega

en 24/48 horas

1,545 €
unitario
(Suministrado en
múltiplos de 10)

15,45 €

Cable plano preparado FFC 30 vías,0.5mm 4589153
Molex
98266-0325
Estado RoHS - Conforme

5

### 5 Disponible para entrega en

24/48 horas

1,608 €
unitario
(Suministrado en
múltiplos de 5)

8,04 €

Forma de envío

Forma de envío | Entrega a domicilio (Cuenta crédito o Tarjeta
crédito/débito). Ver condiciones - Preguntas Frecuentes (parte inferior izquierda)
Total productos | 142,39 €
Entrega | Gratuito
IVA | 29,90 €
Total del pedido | 172,29 €

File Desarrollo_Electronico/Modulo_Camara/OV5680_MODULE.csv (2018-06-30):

Id | Designator | Package | Quantity | Designation | Supplier and ref
1 | REF**,REF**,REF**,REF** | MountingHole_2.5mm_Pad | 4 | MountingHole_2.5mm_Pad
2 | C1,C2,C4,C5,C7 | C_1206_HandSoldering | 5 | 0.1uF
3 | C3,C6 | C_1206_HandSoldering | 2 | 4.7uF
4 | C8,C9,C10,C11,C12,C13,C14,C15,C16,C17,C18,C19,C20,C21,C22,C23,C24,C25 | C_1206_HandSoldering | 18 | 12pF
5 | U1 | SOIC-30-MOD | 1 | OV5680
6 | REF*** | OSHW-Logo2_14.6x12mm_Copper | 1 | OSHW-Logo2_14.6x12mm_Copper
7 | REF*** | KiCad-Logo2_8mm_SilkScreen | 1 | KiCad-Logo2_8mm_SilkScreen
8 | G*** | LOGO | 1 | LOGO
9 | R3 | R_1206_HandSoldering | 1 | 4,7k
10 | R2,R1 | R_1206_HandSoldering | 2 | 4.7k
11 | P1 | Molex-FPC_30 | 1 | CONN_01X30
12 | L1,L2,L3,L5,L6,L7,L8,L9,L11,L12,L4,L10 | R_0603_HandSoldering | 12 | 19nH
13 | D14,D13,D12,D11,D10,D9,D8,D7,D6,D5,D4,D3,D2,D1 | D_SMA_Standard | 14 | ZENER
14 | IC1 | TSSOP-8_4.4x3mm_Pitch0.65mm | 1 | AT24CS02-MAHM

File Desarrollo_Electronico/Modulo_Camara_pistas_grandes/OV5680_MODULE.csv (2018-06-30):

Id | Identificador | Empaquetado | Cantidad | Identificación | Suministrador y ref
1 | REF**,REF**,REF**,REF** | MountingHole_2.5mm_Pad | 4 | MountingHole_2.5mm_Pad
2 | R1,R2 | R_0603_HandSoldering | 2 | 4.7k | https://store.comet.bg/en/Catalogue/Product/28159/
3 | R3 | R_0603_HandSoldering | 1 | 4,7k | https://store.comet.bg/en/Catalogue/Product/28159/
4 | R4,R5 | R_0603_HandSoldering | 2 | 0 | http://uk.farnell.com/yageo/rc0603fr-070rl/res-thick-film-0r-1-0-1w-0603/dp/2309106
5 | IC1 | SOIC-8_3.9x4.9mm_Pitch1.27mm | 1 | AT24CS02-MAHM | https://www.mouser.es/ProductDetail/Atmel/AT24CS02-SSHM-B/?qs=YAvGbpKWXiSbI%252bYR%252bSoH%252bA==
6 | C1,C2,C4,C5,C7 | C_1206_HandSoldering | 5 | 0.1uF | https://www.mouser.es/ProductDetail/AVX/12066D104KAT4A?qs=sGAEpiMZZMs0AnBnWHyRQHBIeb04j8IHWnPONqCDu8A%3d
7 | C3,C6 | C_1206_HandSoldering | 2 | 4.7uF | https://www.mouser.es/ProductDetail/Wurth-Electronics/885012208002
8 | C8,C9,C10,C11,C12,C13,C14,C15,C16,C17,C18,C19,C20,C21,C22,C23,C24,C25 | C_1206_HandSoldering | 18 | 12pF | https://www.mouser.es/ProductDetail/Vishay-Vitramon/VJ1206A120FXQCW1BC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
9 | D1,D2,D3,D4,D5,D6,D7,D8,D9,D10,D11,D12,D13,D14 | D_0805 | 14 | ZENER | https://www.mouser.es/ProductDetail/Taiwan-Semiconductor/BZY55C4V7
10 | L1,L2,L3,L4,L5,L6,L7,L8,L9,L10,L11,L12 | SELF-WE-TPC_M | 12 | 19nH | https://www.mouser.es/ProductDetail/Murata-Electronics/LQW18AN19NJ80D
11 | P1 | CABLINE-VS-I-PEX | 1 | CONN_01X30 | https://www.i-pex.com/Products/detail/25
12 | U1 | SOIC-30-MOD | 1 | OV5680
13 | REF*** | OSHW-Logo2_14.6x12mm_Copper | 1 | OSHW-Logo2_14.6x12mm_Copper
14 | REF*** | KiCad-Logo2_8mm_SilkScreen | 1 | KiCad-Logo2_8mm_SilkScreen
15 | G*** | LOGO | 1 | LOGO

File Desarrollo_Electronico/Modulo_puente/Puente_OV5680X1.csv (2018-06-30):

Id | Designator | Package | Quantity | Designation | Supplier and ref
1 | REF**,REF**,REF** | MountingHole_3.2mm_M3 | 3 | MountingHole_3.2mm_M3
2 | REF*** | OSHW-Logo2_9.8x8mm_SilkScreen | 1 | OSHW-Logo2_9.8x8mm_SilkScreen
3 | REF*** | KiCad-Logo2_12mm_SilkScreen | 1 | KiCad-Logo2_12mm_SilkScreen
4 | C1 | C_1206_HandSoldering | 1 | 0.1uF
5 | U1 | TSSOP-8_4.4x3mm_Pitch0.65mm | 1 | AT24CS02-MAHM
6 | R5,R4,R3 | R_1206_HandSoldering | 3 | 4,7k
7 | J1 | Molex-FPC_30 | 1 | Conn_01x30
8 | P1 | QTH-060-01-H-D-A | 1 | QTH-060-01-H-D-A

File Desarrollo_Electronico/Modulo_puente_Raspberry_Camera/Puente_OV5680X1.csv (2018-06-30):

Id | Identificador | Empaquetado | Cantidad | Identificación | Suministrador y ref
1 | REF**,REF**,REF** | MountingHole_3.2mm_M3 | 3 | MountingHole_3.2mm_M3
2 | U1 | SOIC-8_3.9x4.9mm_Pitch1.27mm | 1 | AT24CS02-MAHM | https://www.mouser.es/ProductDetail/Atmel/AT24CS02-SSHM-B/?qs=YAvGbpKWXiSbI%252bYR%252bSoH%252bA==
3 | C1 | C_0805_HandSoldering | 1 | 0.1uF | https://www.mouser.es/ProductDetail/Taiyo-Yuden/LMK212SD104JG-T
4 | R1,R2 | R_0805_HandSoldering | 2 | 0 | https://www.mouser.es/ProductDetail/Vishay-Draloric/CRCW08050000Z0EAHP?qs=pTGEtN%252bMLlDLrJUqQmN2jA%3d%3d
5 | R3,R4,R5 | R_0805_HandSoldering | 3 | 4,7k | https://store.comet.bg/en/Catalogue/Product/22769/
6 | J1 | CABLINE-VS-I-PEX | 1 | Conn_01x30 | https://www.i-pex.com/Products/detail/25
7 | P1 | QTH-060-01-H-D-A | 1 | QTH-060-01-H-D-A | https://www.digikey.com/product-detail/en/samtec-inc/QTH-060-01-H-D-A/SAM12792-ND/6695553
8 | REF*** | OSHW-Logo2_9.8x8mm_SilkScreen | 1 | OSHW-Logo2_9.8x8mm_SilkScreen
9 | REF*** | KiCad-Logo2_12mm_SilkScreen | 1 | KiCad-Logo2_12mm_SilkScreen

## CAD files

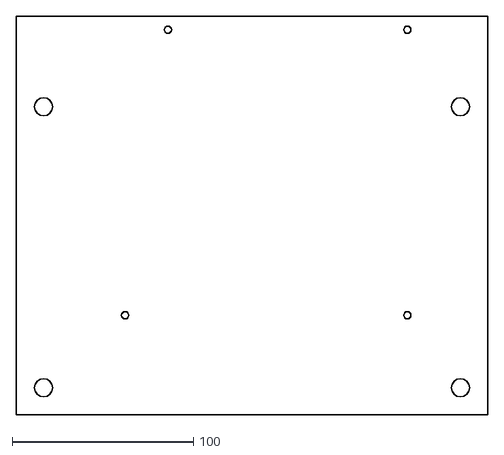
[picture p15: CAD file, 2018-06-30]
Desarrollo_Electronico/Soporte_Jetson/Soporte_V2.dxf
260.0 x 220.0

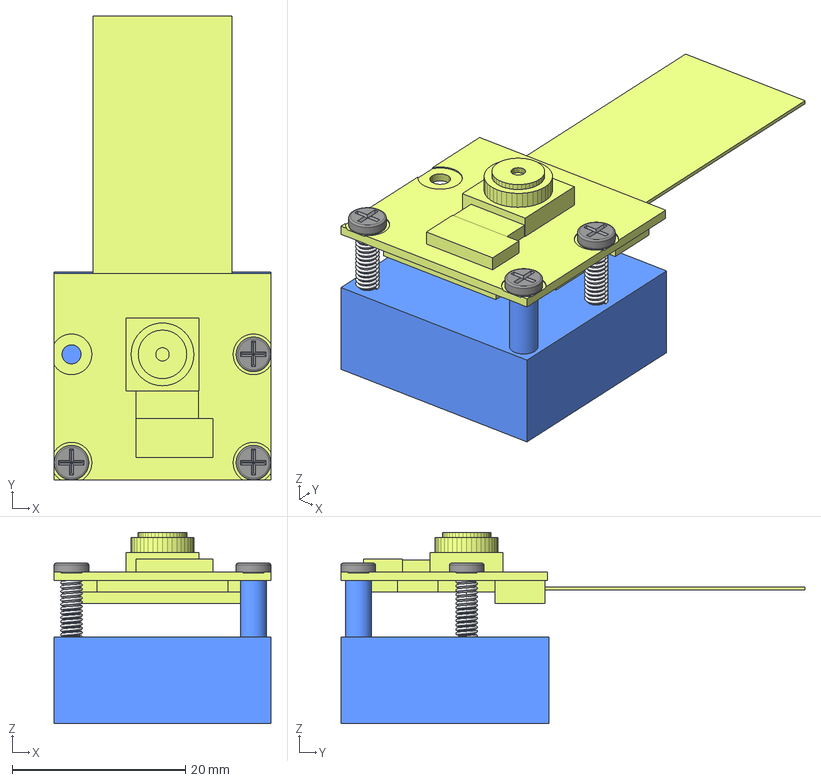
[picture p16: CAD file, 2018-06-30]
Desarrollo_Mecanico/Ajuste_angulo_camaras/Ajustador_V1.fcstd
25.0 x 53.5 x 22.1 mm
Tornillo001
Tornillo002
Tornillo003
Resorte001
Resorte002
RPiCam_v2002

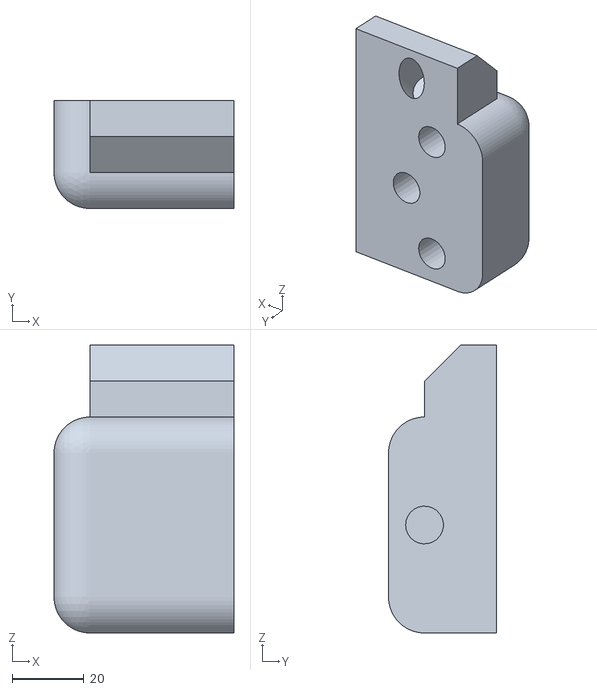
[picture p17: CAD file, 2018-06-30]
Desarrollo_Mecanico/Array /Versión V1.1/Soporte_sup_izq.obj
50.0 x 30.0 x 80.0

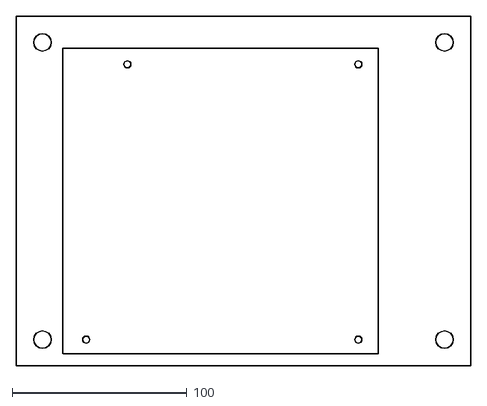
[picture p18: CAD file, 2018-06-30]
Desarrollo_Electronico/Soporte_Jetson/Soporte.dxf
260.0 x 200.0

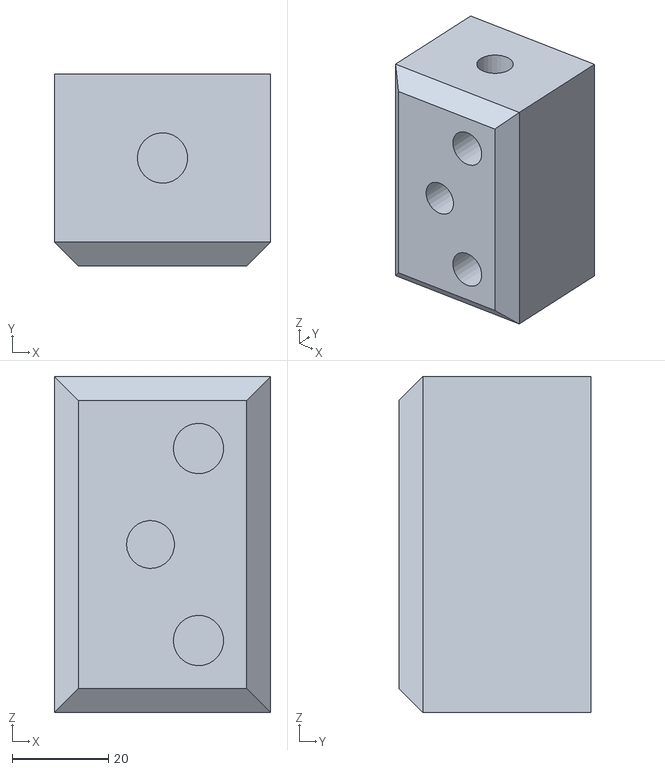
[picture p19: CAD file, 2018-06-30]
Desarrollo_Mecanico/Array /Versión V1.1/Soporte_suelo_der.obj
45.0 x 40.0 x 70.0

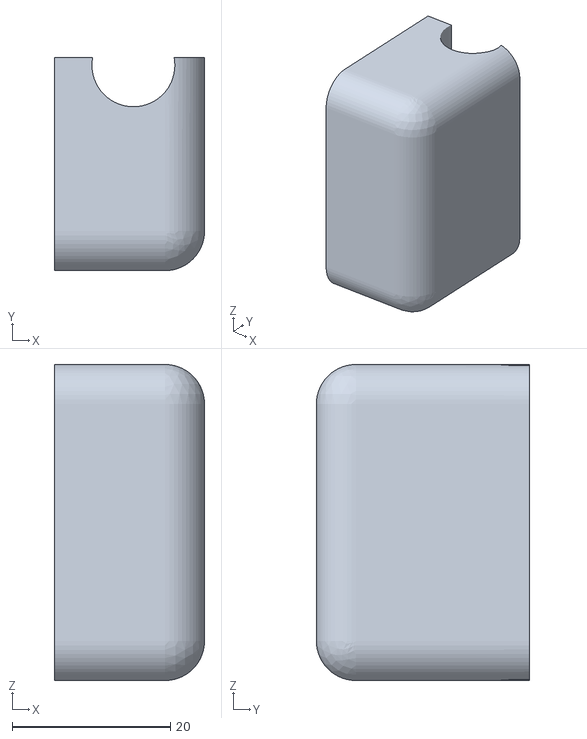
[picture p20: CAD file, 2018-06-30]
Desarrollo_Mecanico/Array /Versión V1.1/Soporte_Jetson.obj
19.0 x 27.0 x 40.0

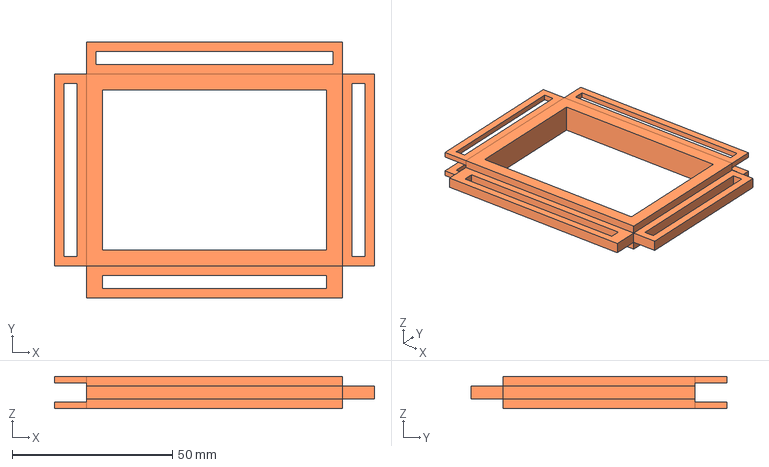
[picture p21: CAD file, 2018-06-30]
Desarrollo_Mecanico/Array /Versión V1.1/Pieza.fcstd
100.0 x 80.0 x 10.0 mm

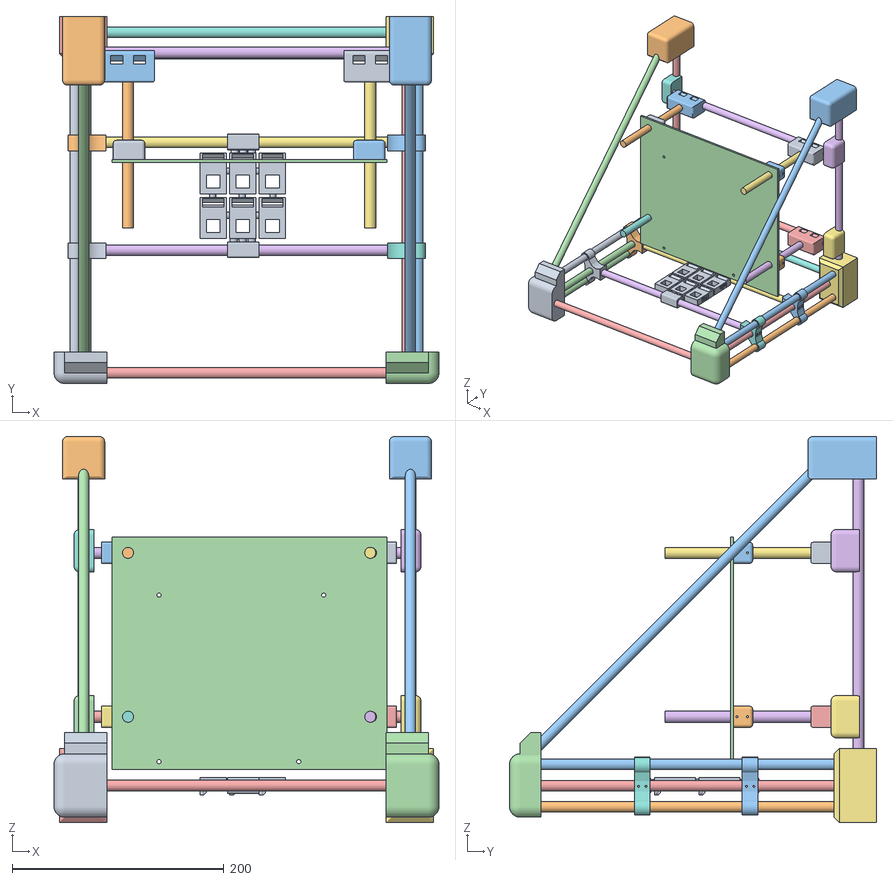
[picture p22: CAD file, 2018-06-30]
Desarrollo_Mecanico/Array /Versión V1.1/Soporte_completo.obj
364.0 x 347.0 x 365.0
Completo001001

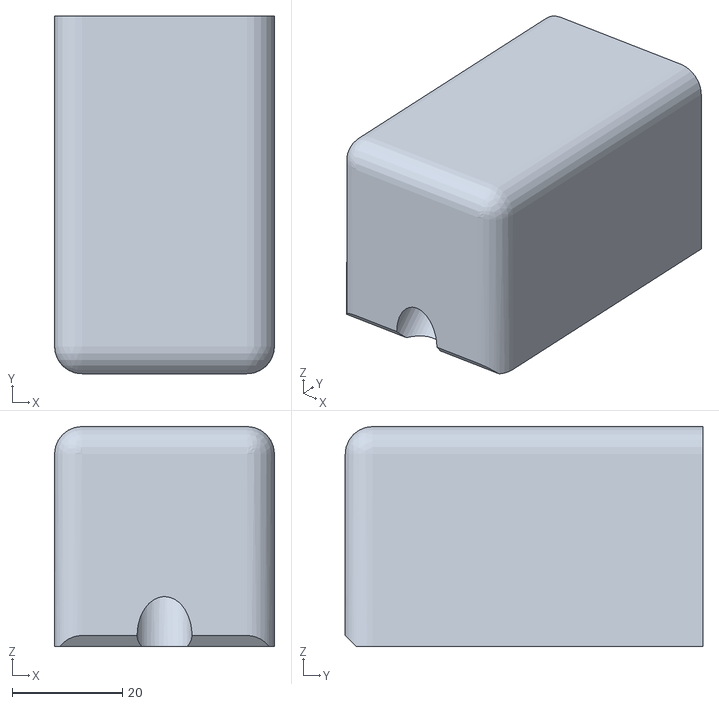
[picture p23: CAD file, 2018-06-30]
Desarrollo_Mecanico/Array /Versión V1.1/Pilar_trasero.obj
40.0 x 65.0 x 40.0

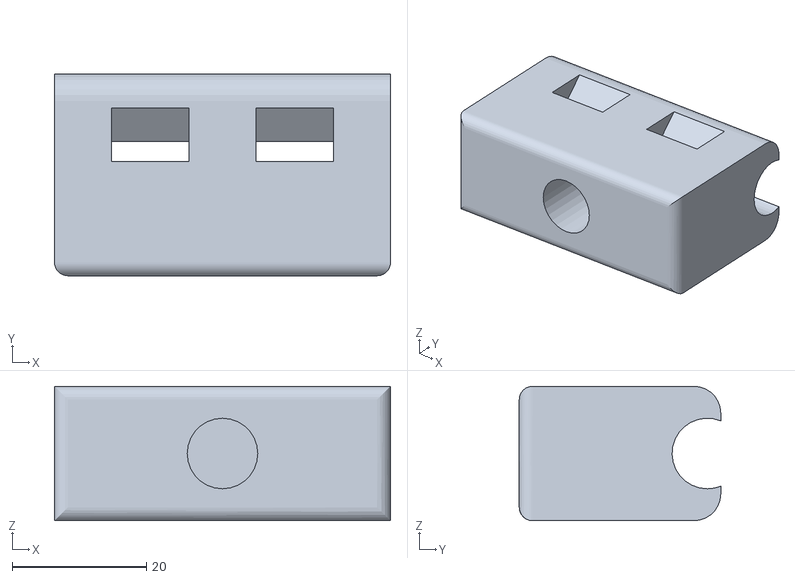
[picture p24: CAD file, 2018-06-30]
Desarrollo_Mecanico/Array /Versión V1.1/Soporte_tubo_cama_Jetson.obj
50.0 x 30.0 x 20.0

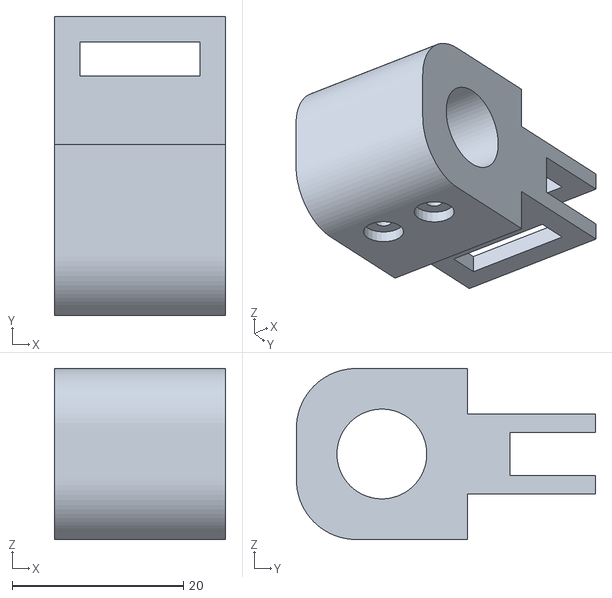
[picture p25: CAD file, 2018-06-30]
Desarrollo_Mecanico/Array /Versión V1.1/Pinza_hembra.obj
20.0 x 35.0 x 20.0

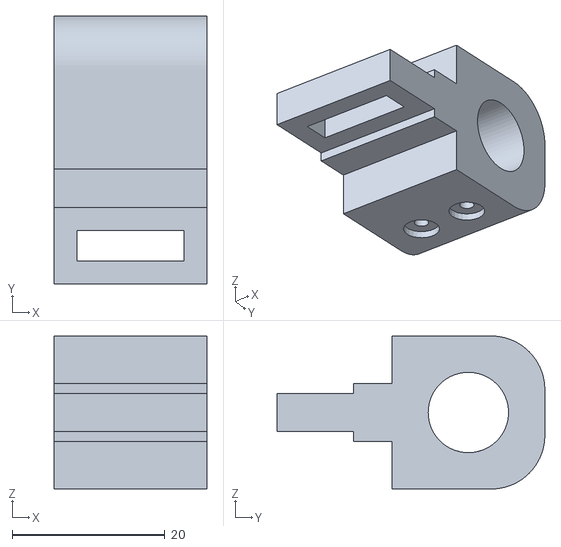
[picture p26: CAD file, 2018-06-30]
Desarrollo_Mecanico/Array /Versión V1.1/Pinza_macho.obj
20.0 x 35.0 x 20.0

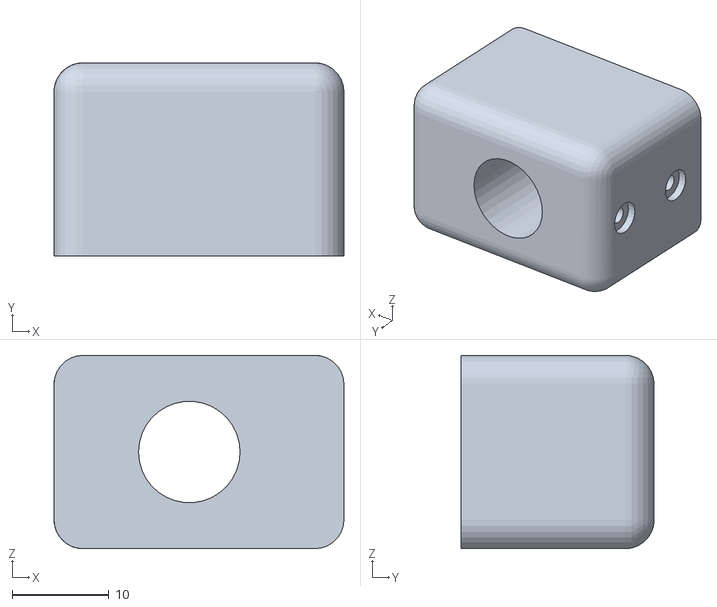
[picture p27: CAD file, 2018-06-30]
Desarrollo_Mecanico/Array /Versión V1.1/Soporte_cama_Jetson.obj
30.0 x 20.0 x 20.0

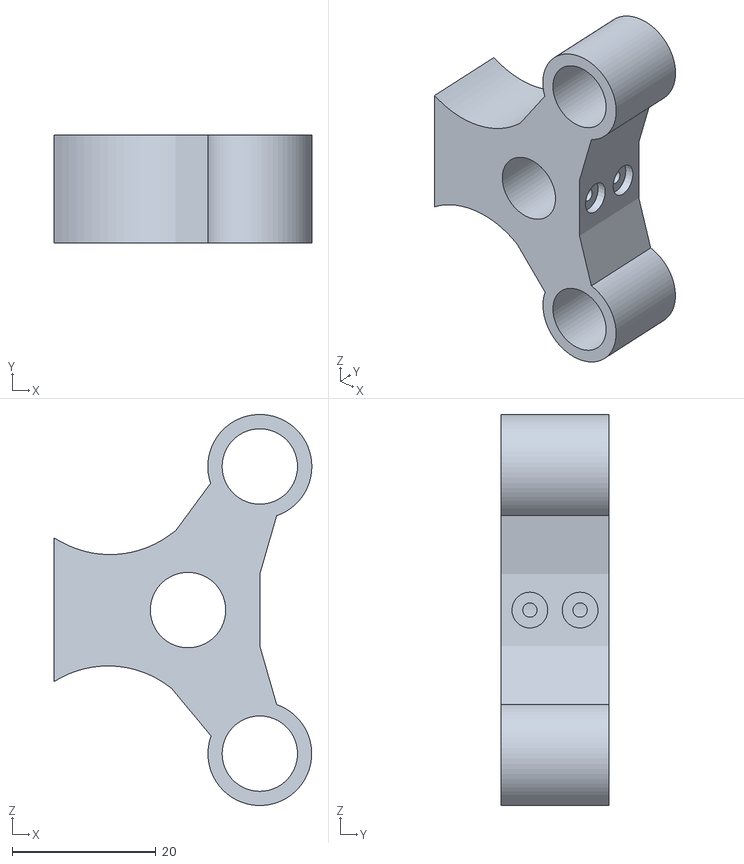
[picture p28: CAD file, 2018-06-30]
Desarrollo_Mecanico/Array /Versión V1.1/Soporte_tubo.obj
35.9 x 15.0 x 54.5

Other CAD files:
Desarrollo_Mecanico/Plantillas_Planos/A3_Landscape.dxf
Desarrollo_Mecanico/Plantillas_Planos/A4_Landscape.dxf
Desarrollo_Mecanico/Array /Versión V1.1/Soporte_sup_der.obj
Desarrollo_Mecanico/Array /Versión V1.1/Soporte_suelo_izq.obj

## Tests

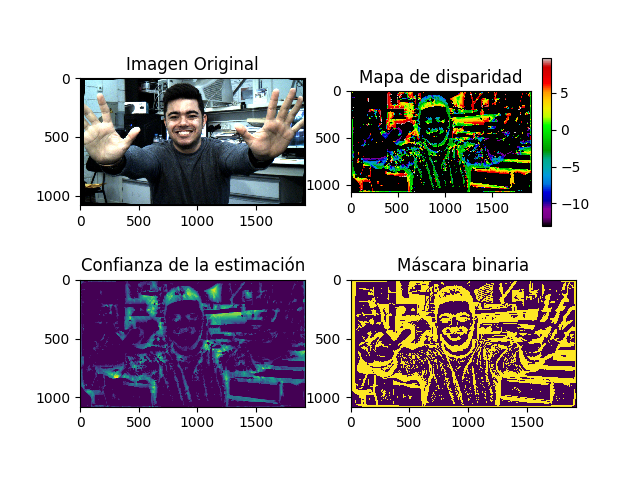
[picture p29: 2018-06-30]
images/Resultados/figure-self.png

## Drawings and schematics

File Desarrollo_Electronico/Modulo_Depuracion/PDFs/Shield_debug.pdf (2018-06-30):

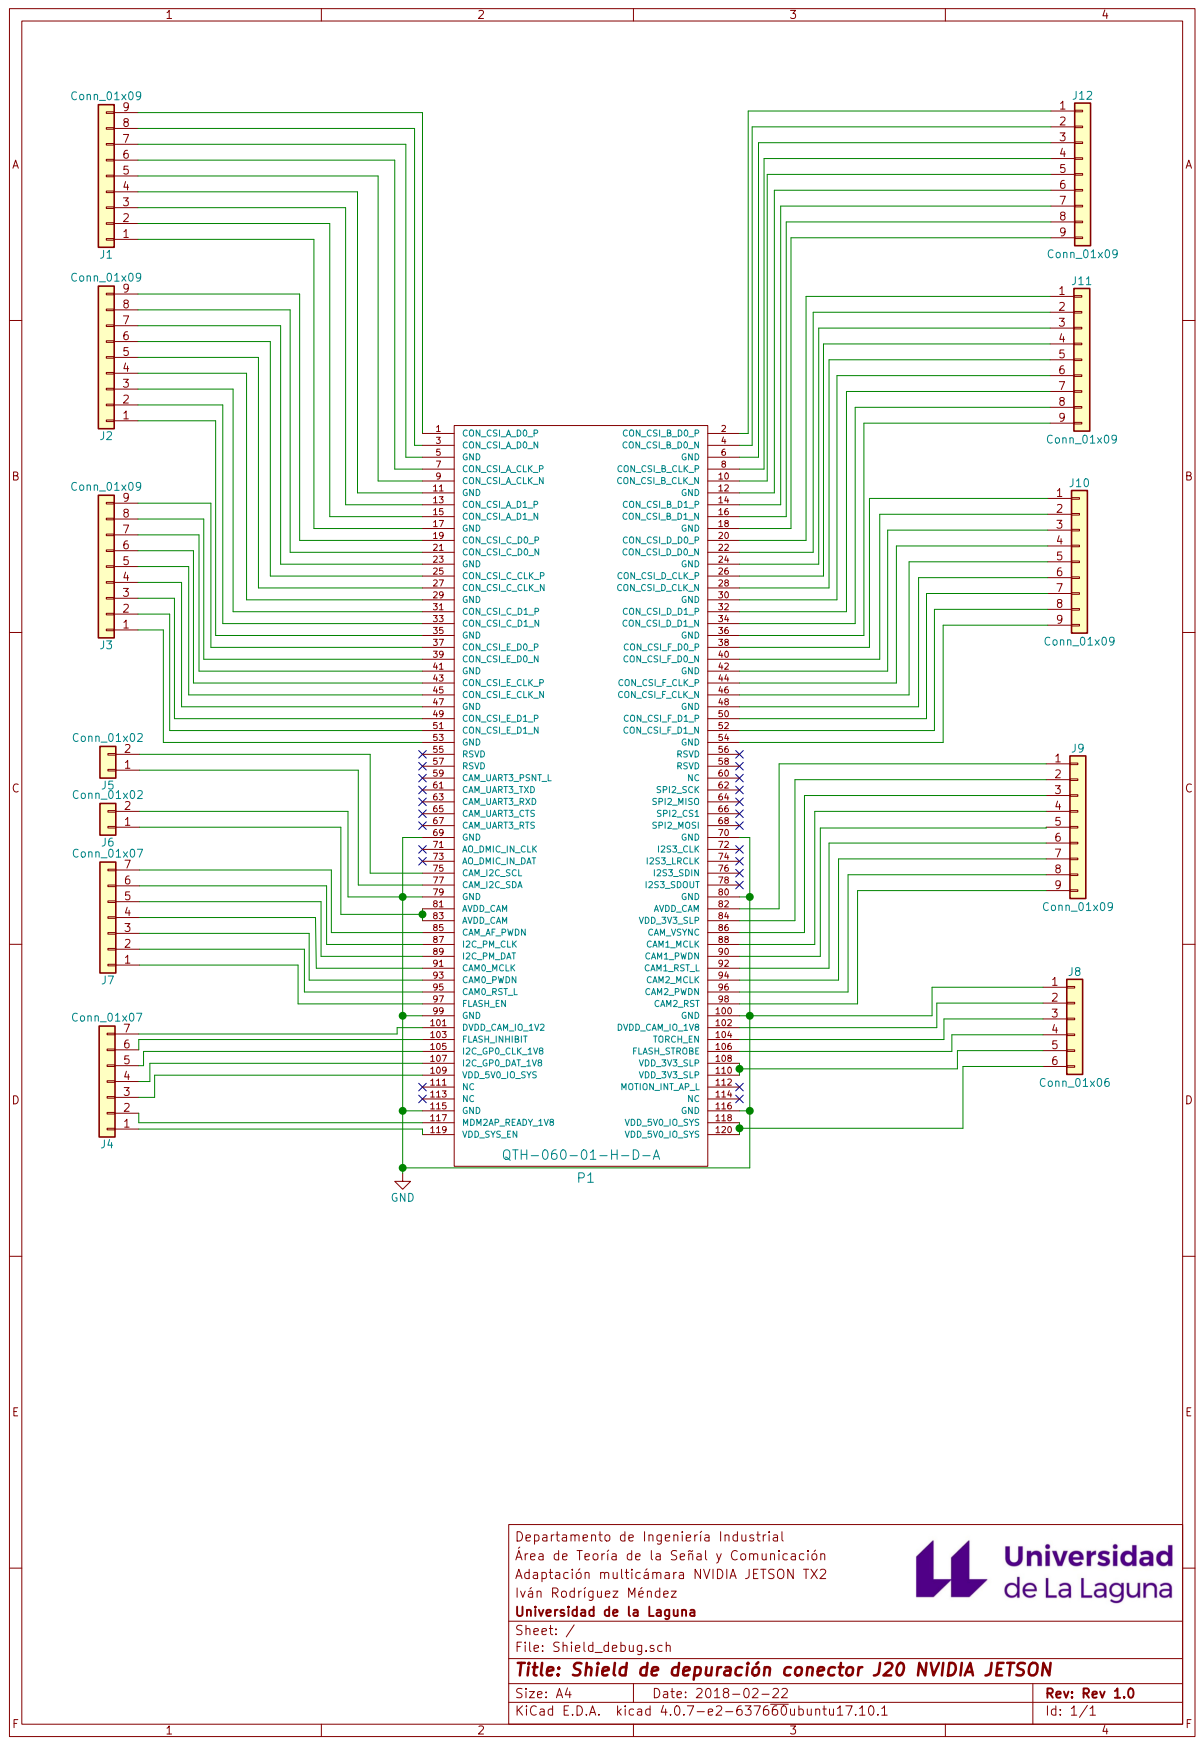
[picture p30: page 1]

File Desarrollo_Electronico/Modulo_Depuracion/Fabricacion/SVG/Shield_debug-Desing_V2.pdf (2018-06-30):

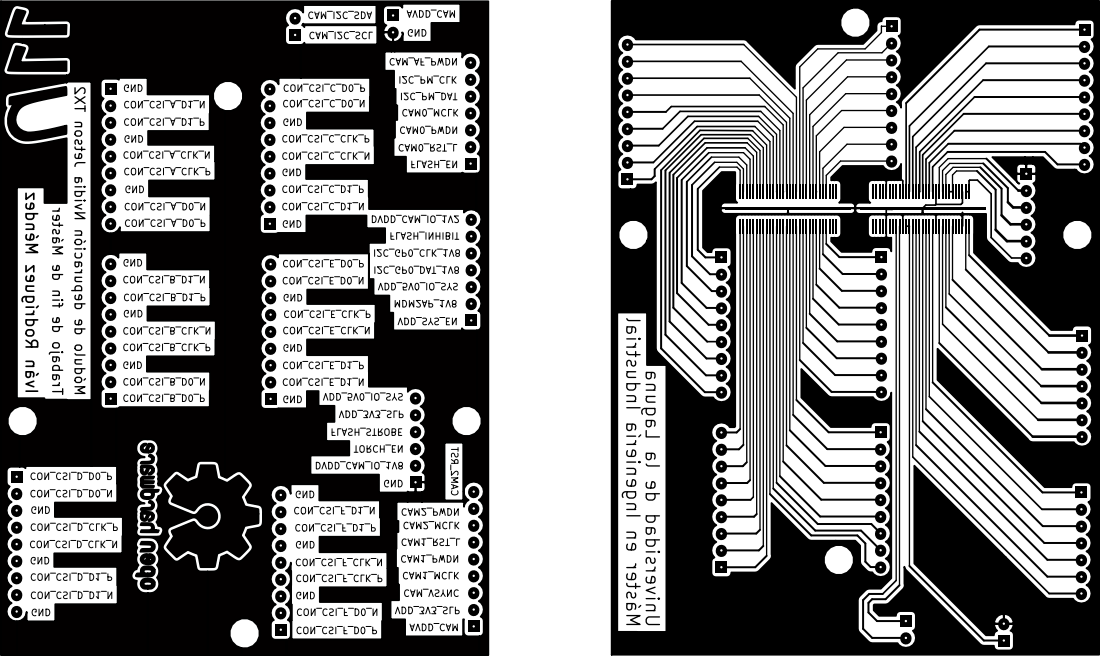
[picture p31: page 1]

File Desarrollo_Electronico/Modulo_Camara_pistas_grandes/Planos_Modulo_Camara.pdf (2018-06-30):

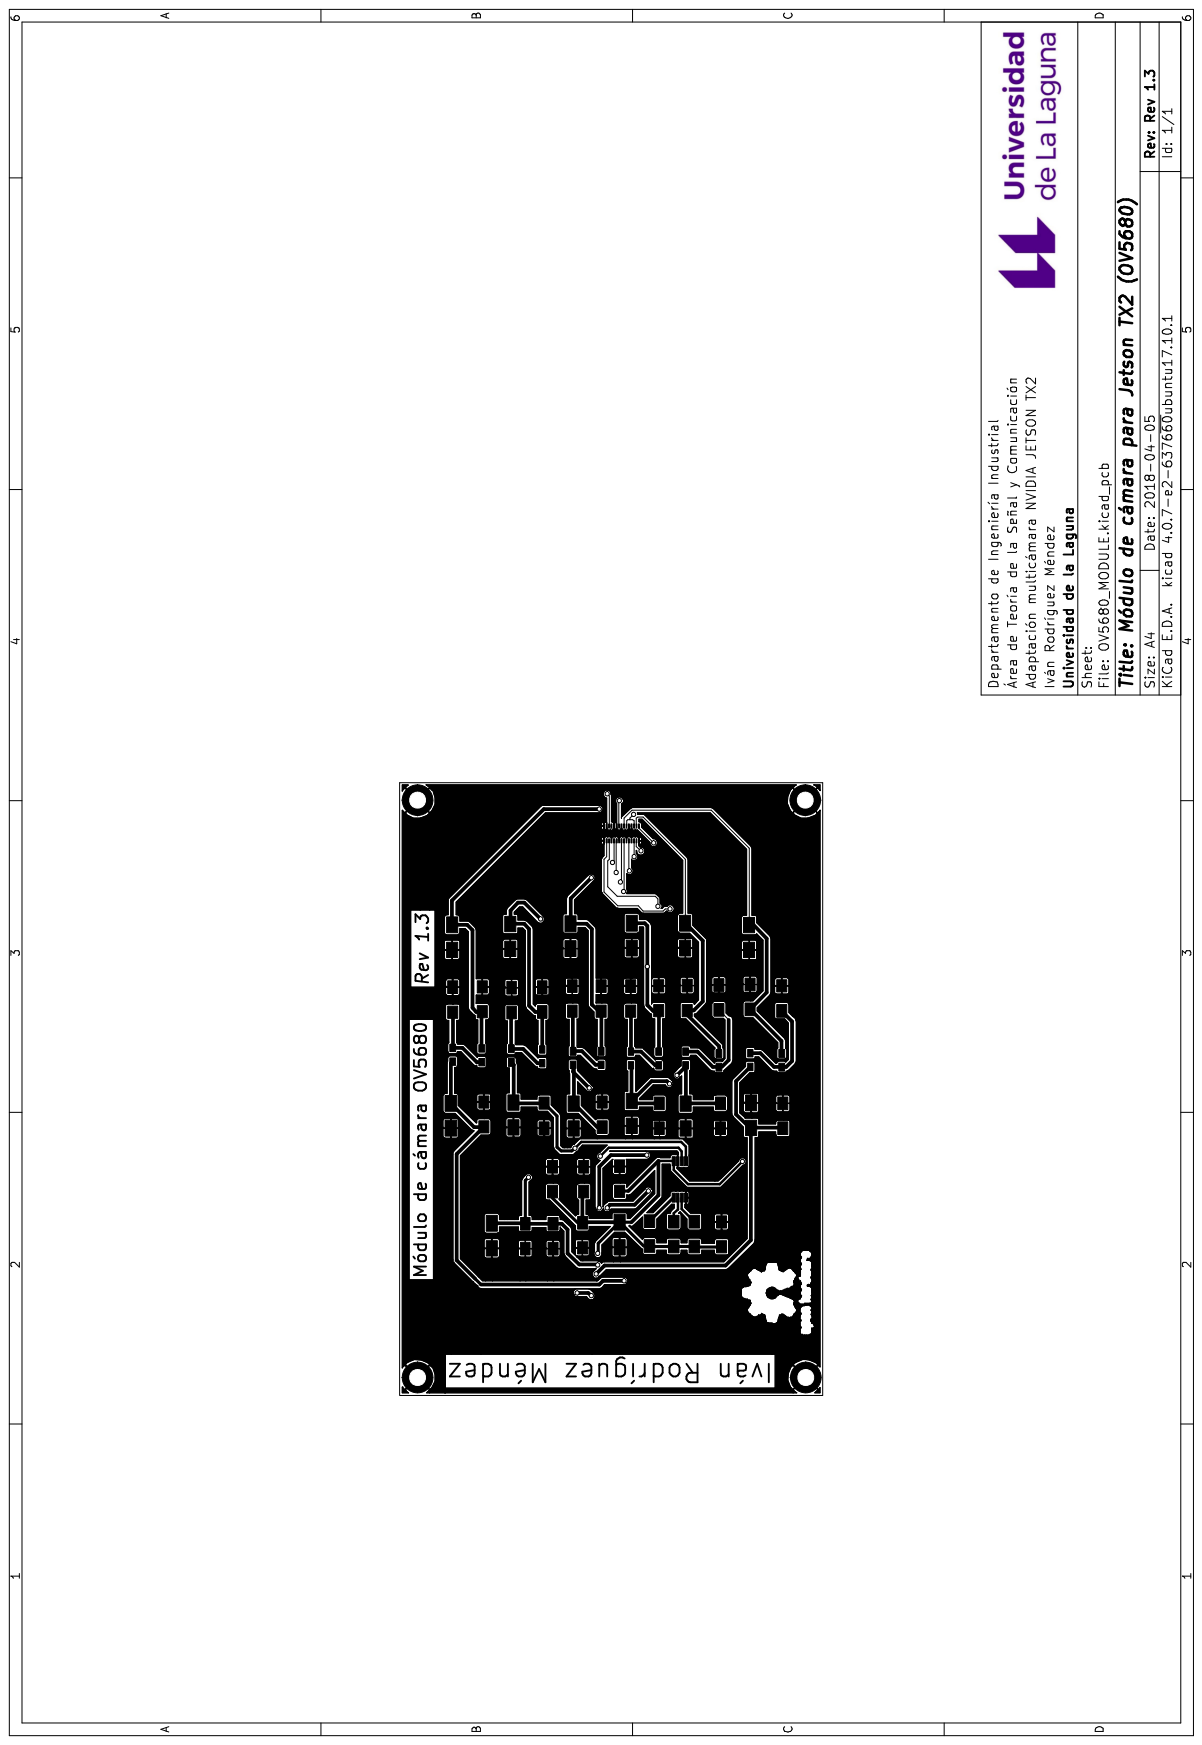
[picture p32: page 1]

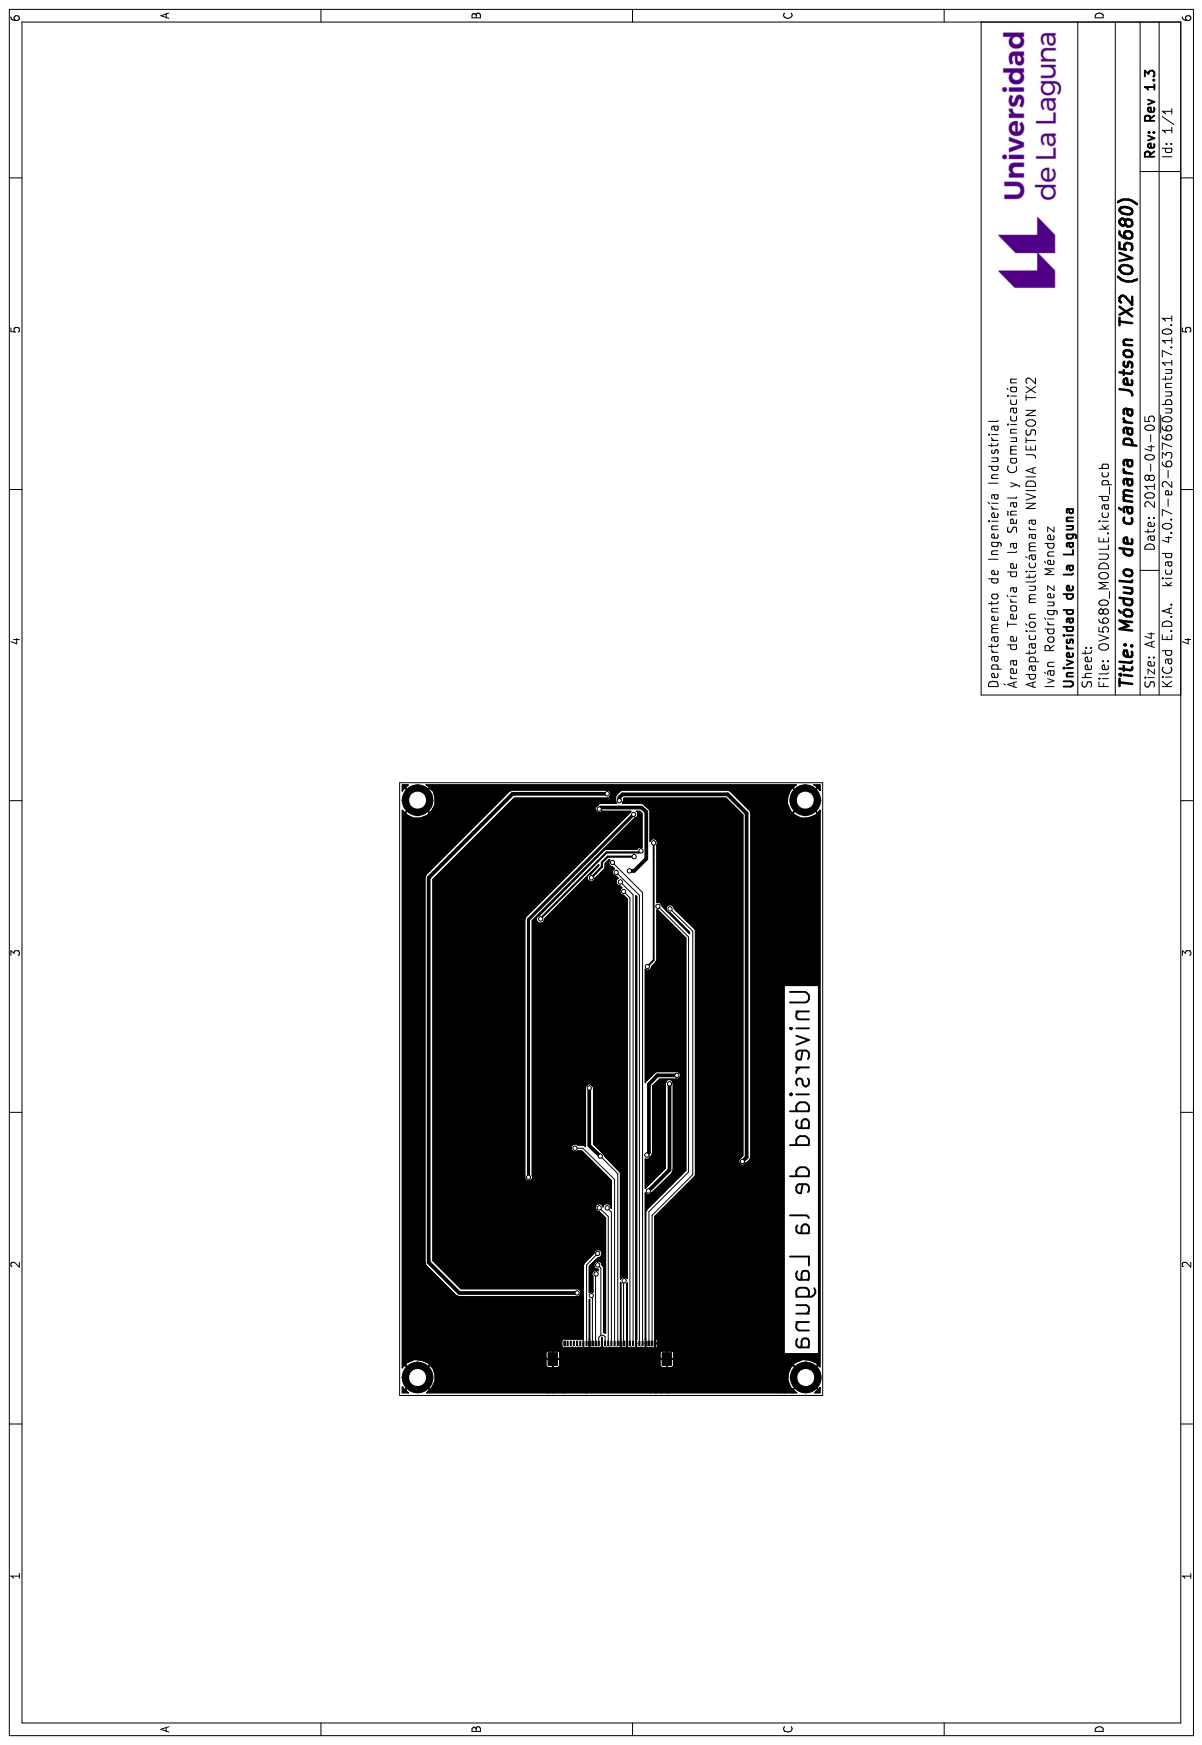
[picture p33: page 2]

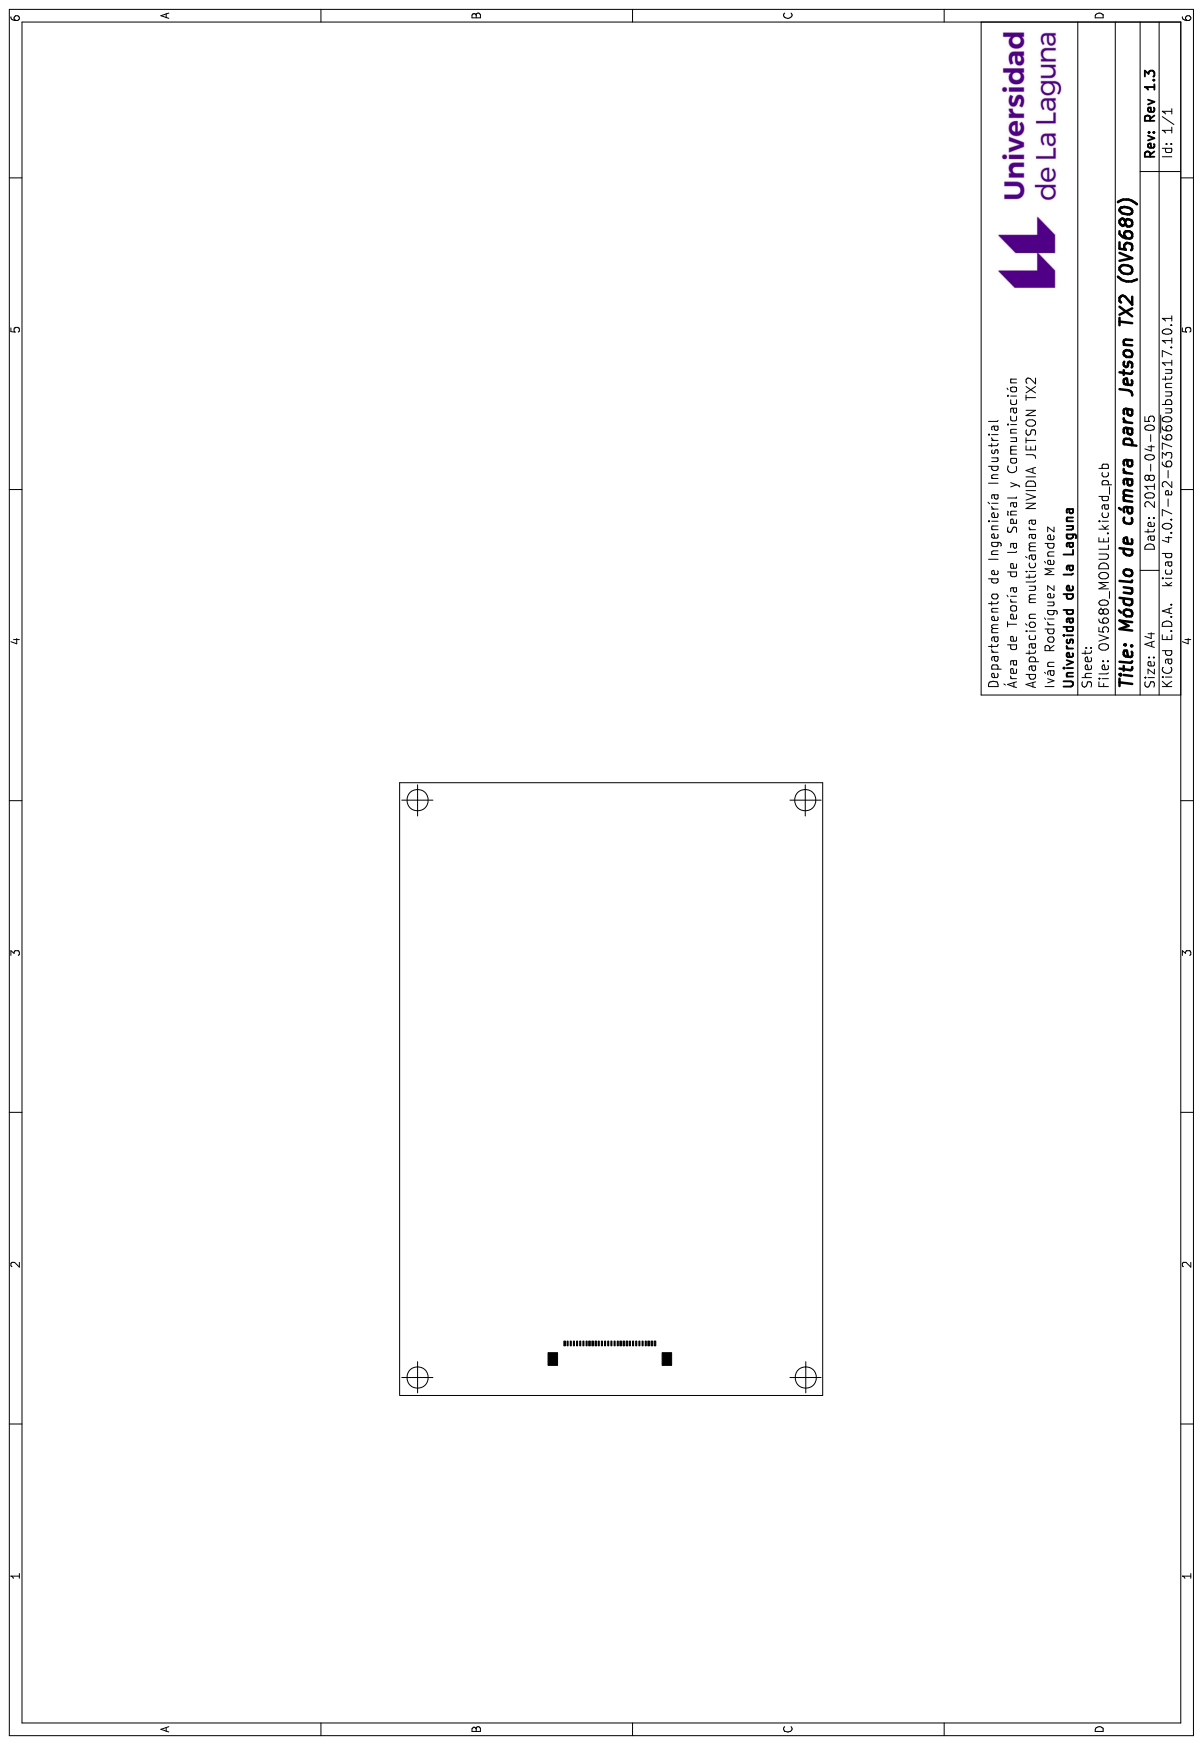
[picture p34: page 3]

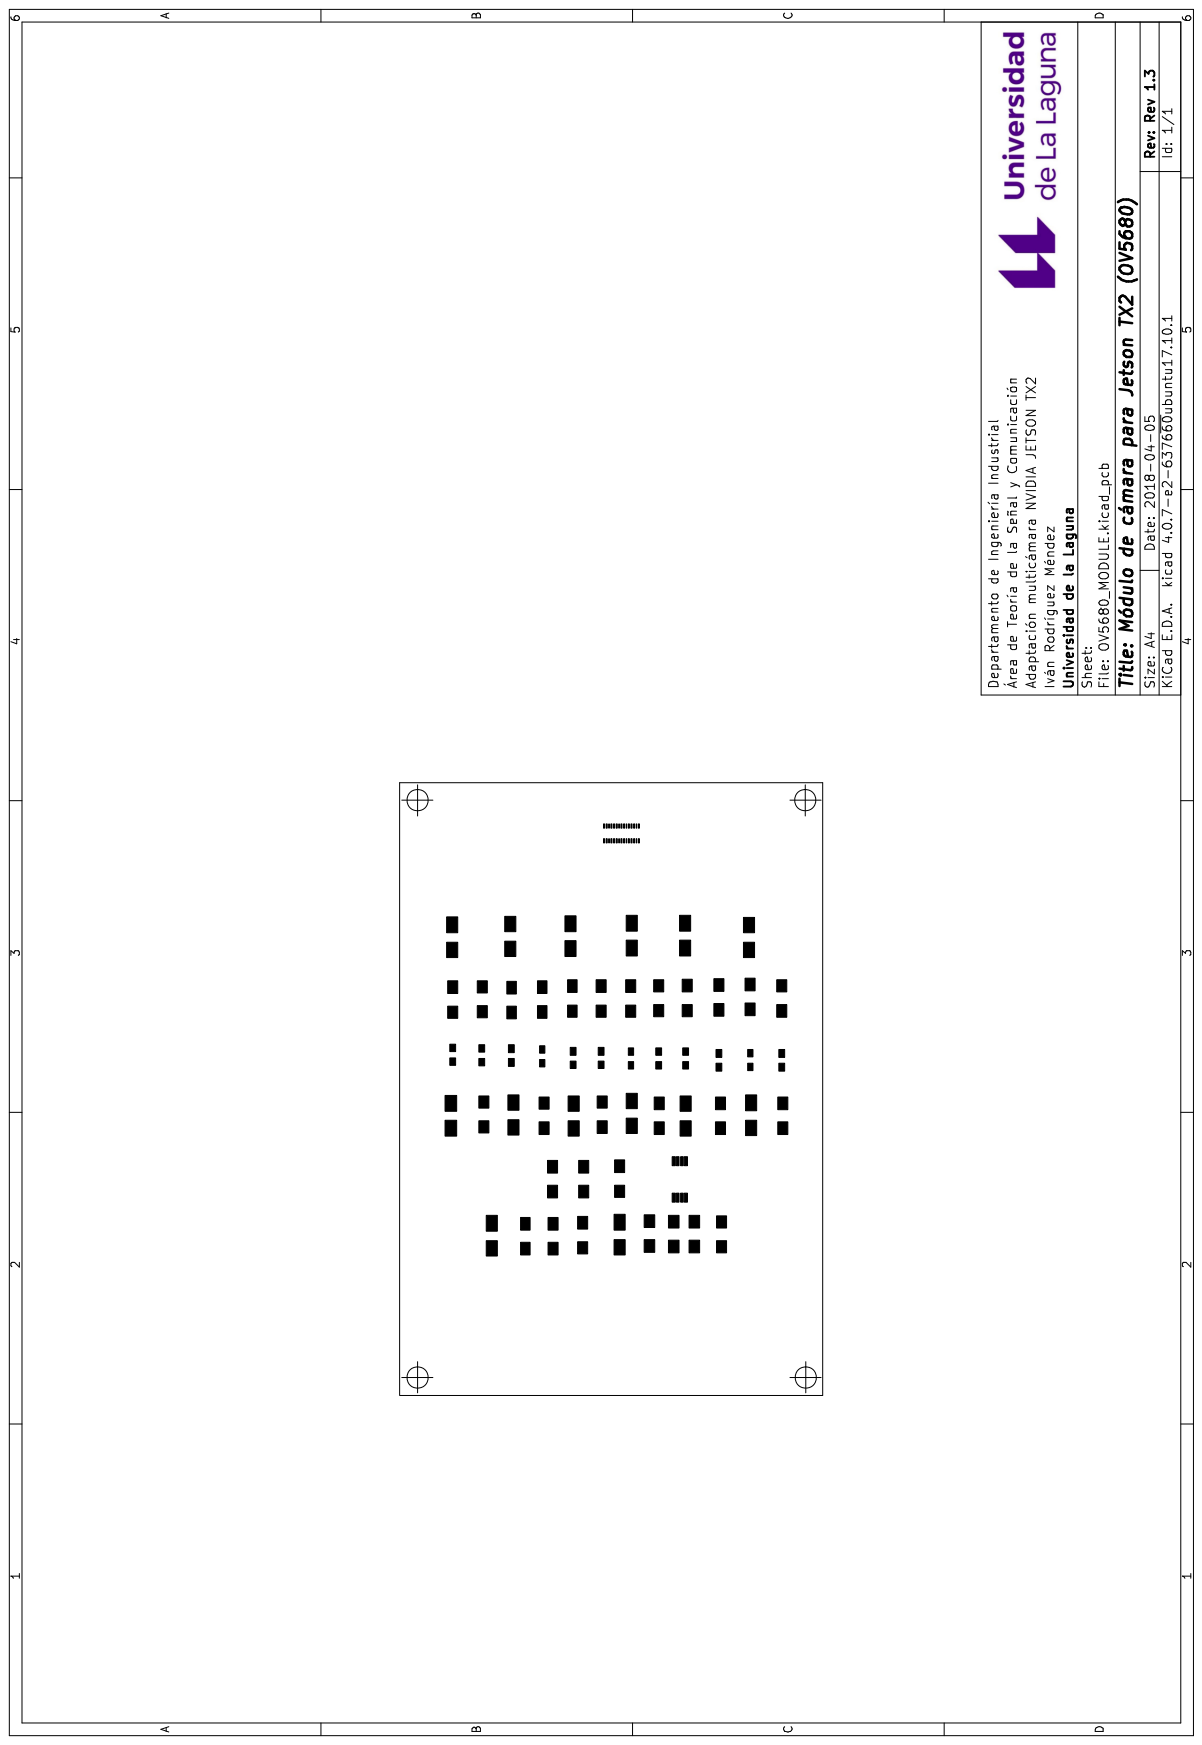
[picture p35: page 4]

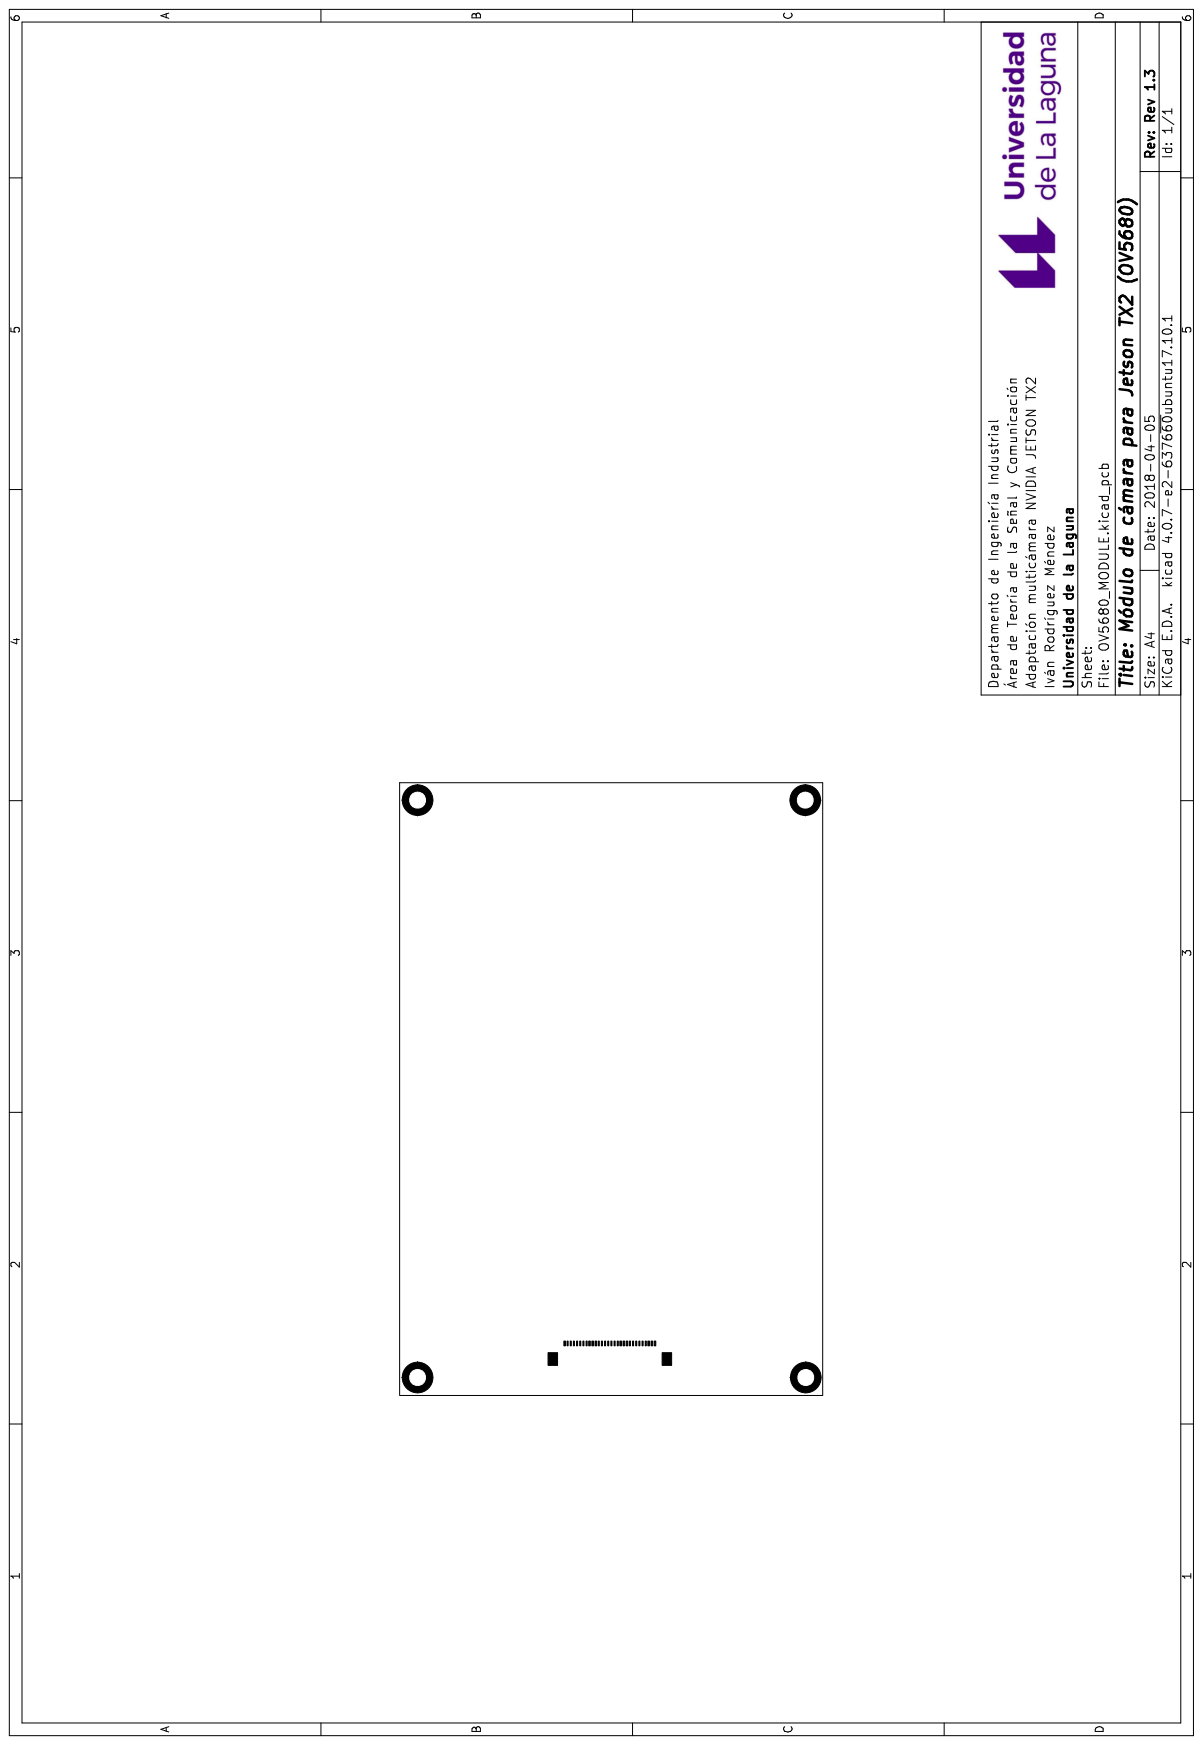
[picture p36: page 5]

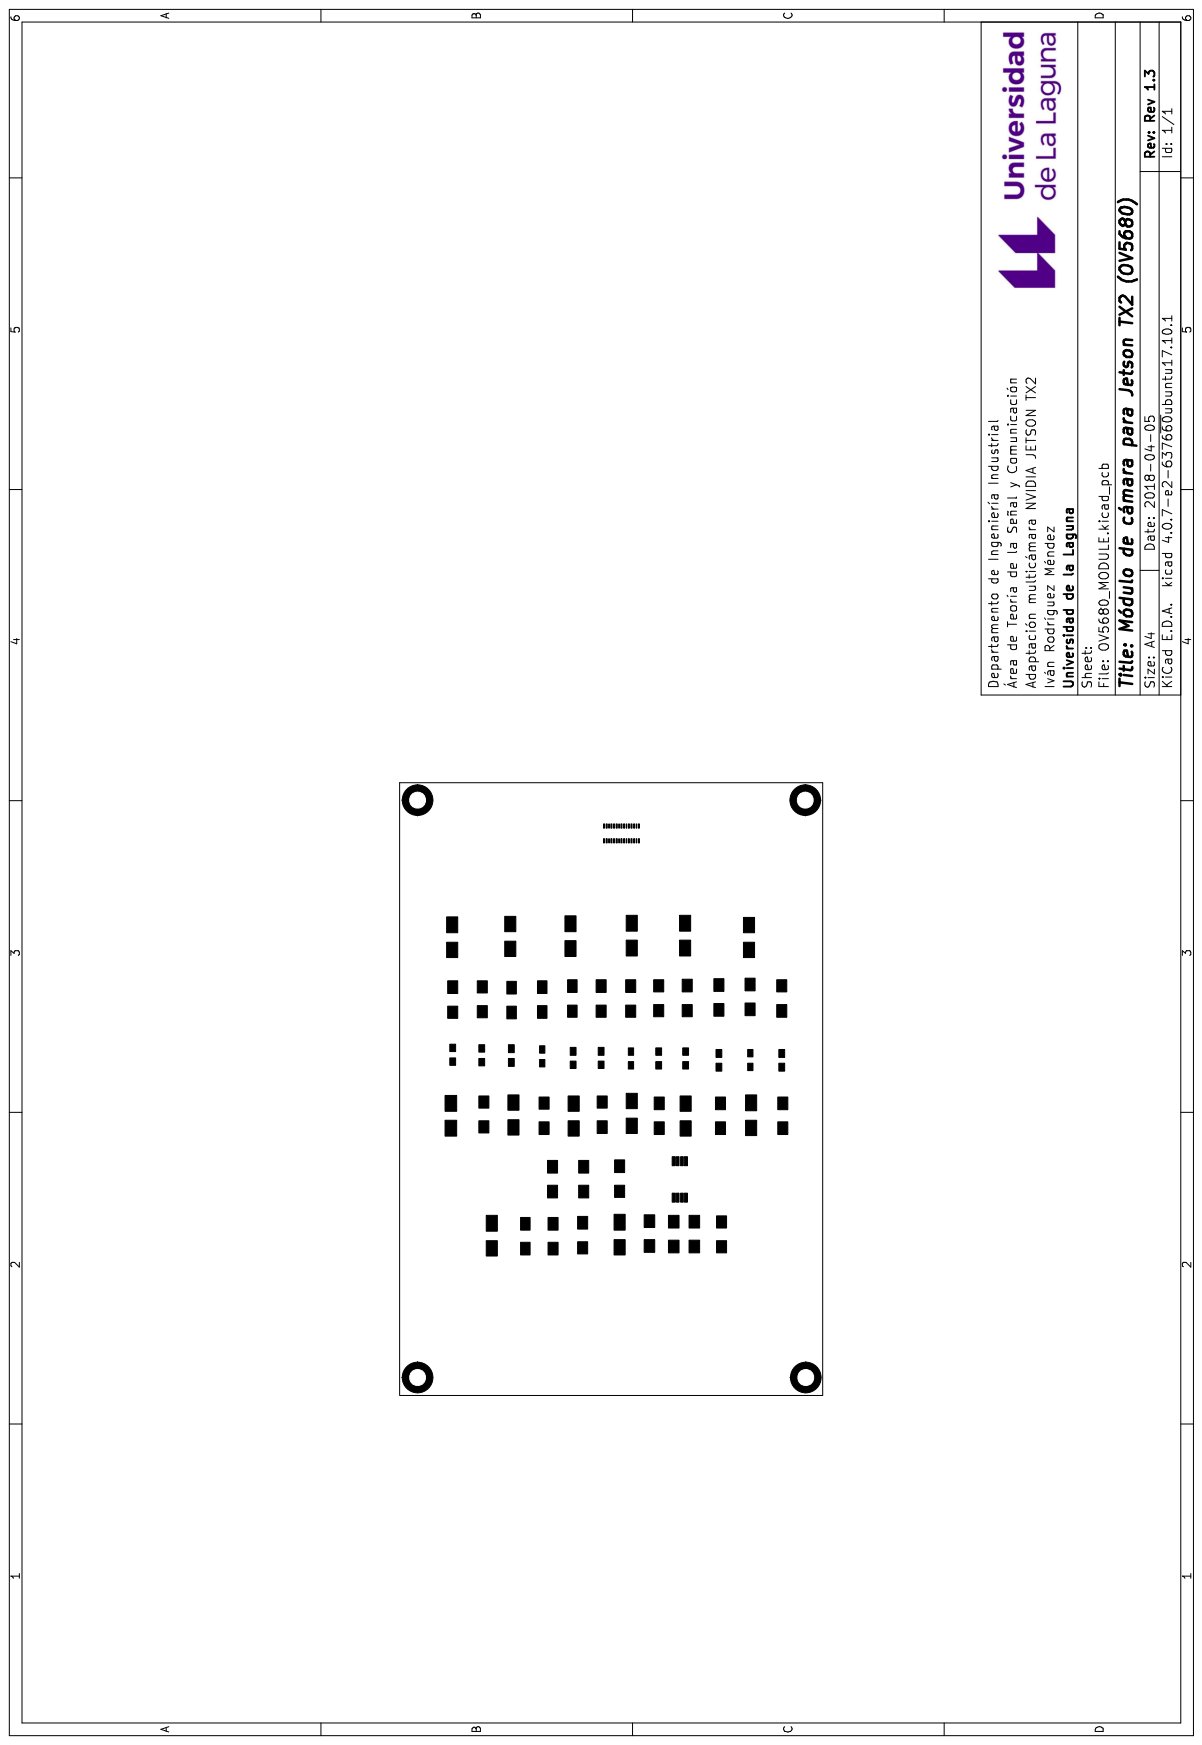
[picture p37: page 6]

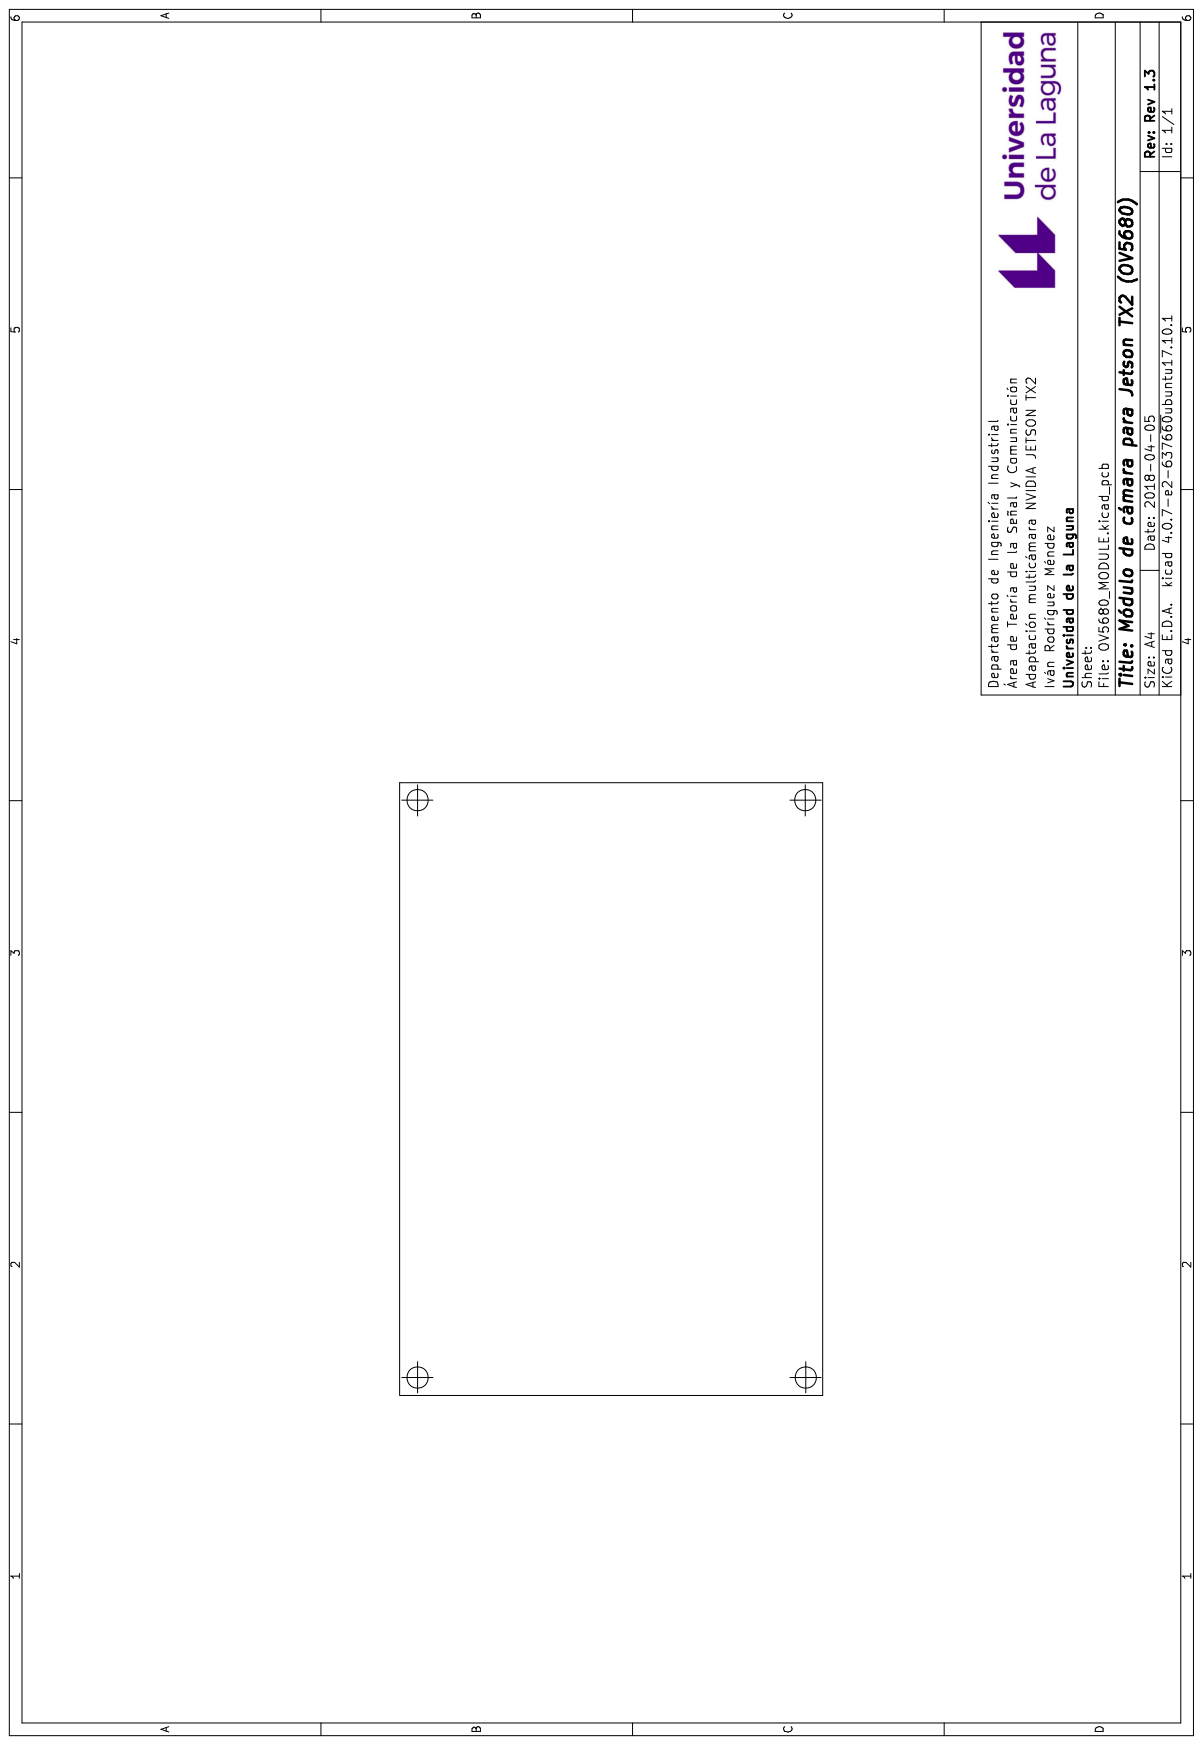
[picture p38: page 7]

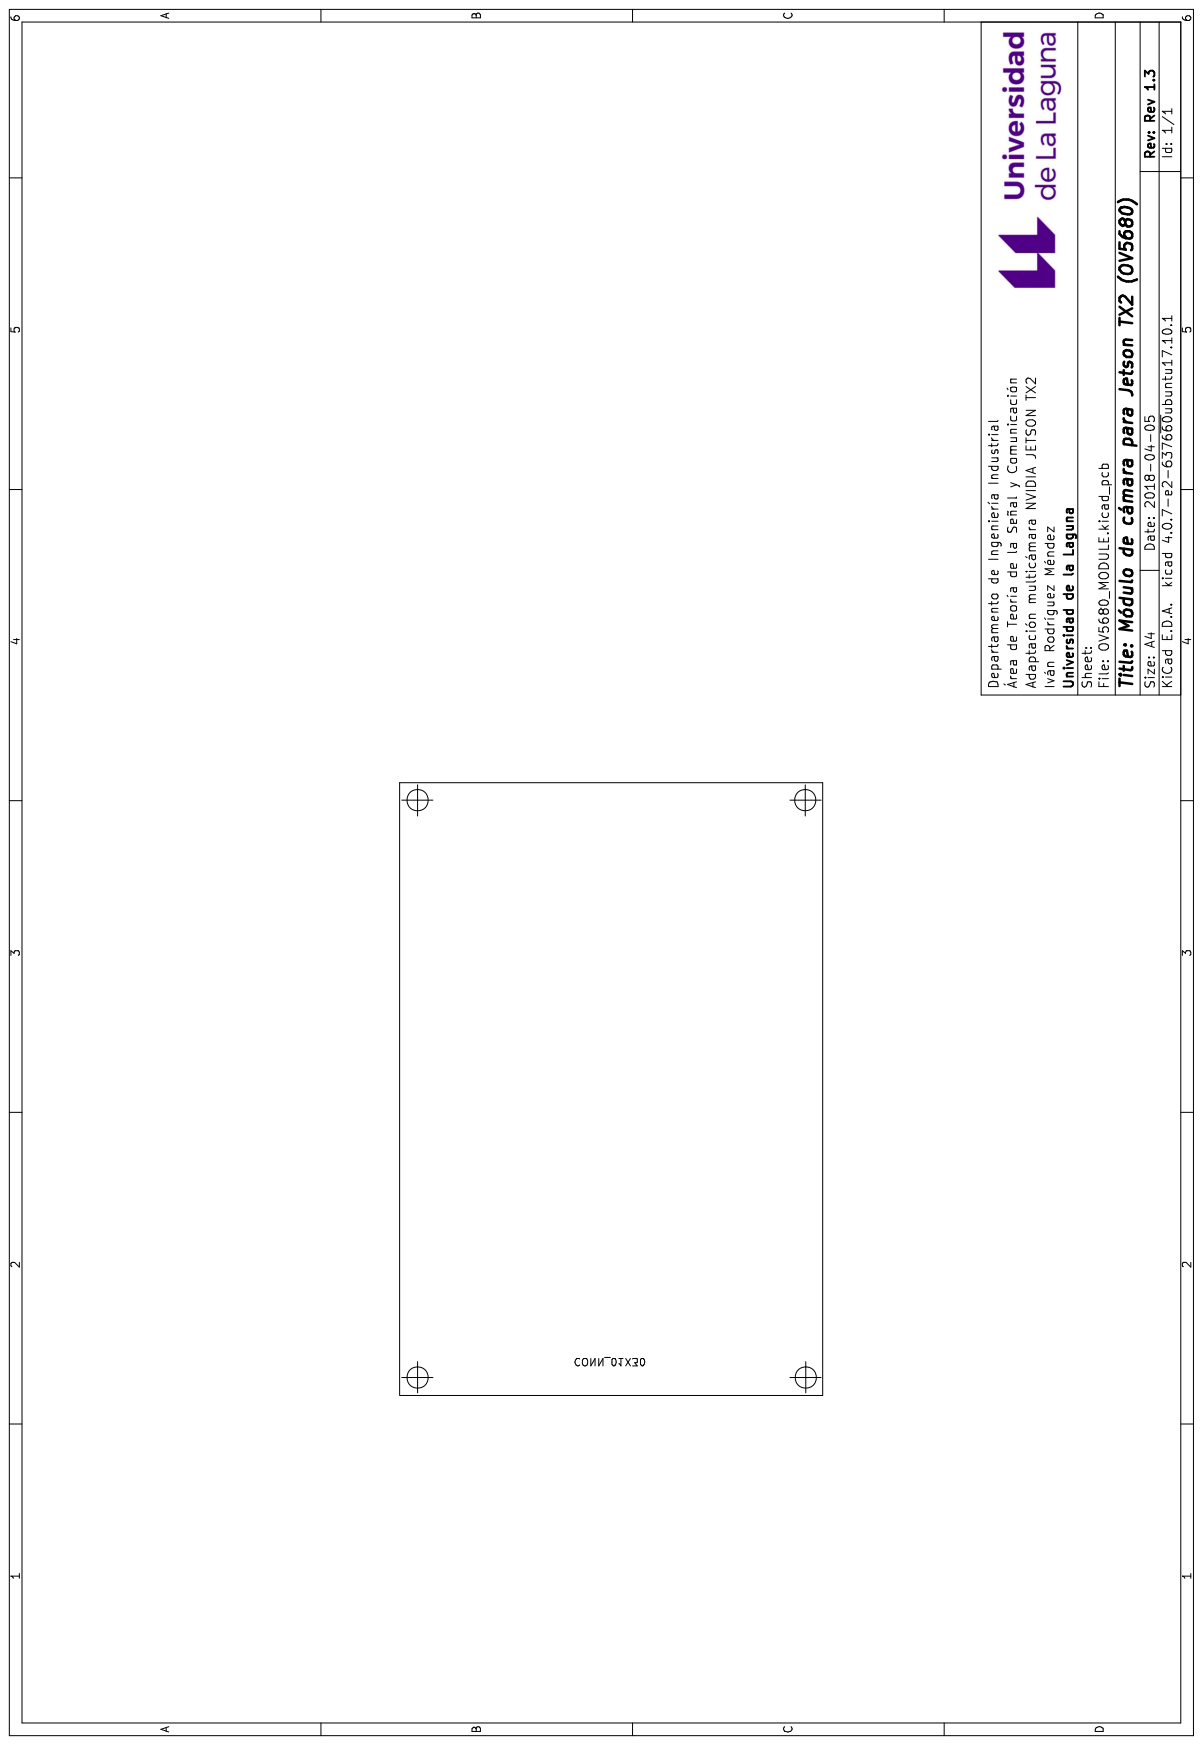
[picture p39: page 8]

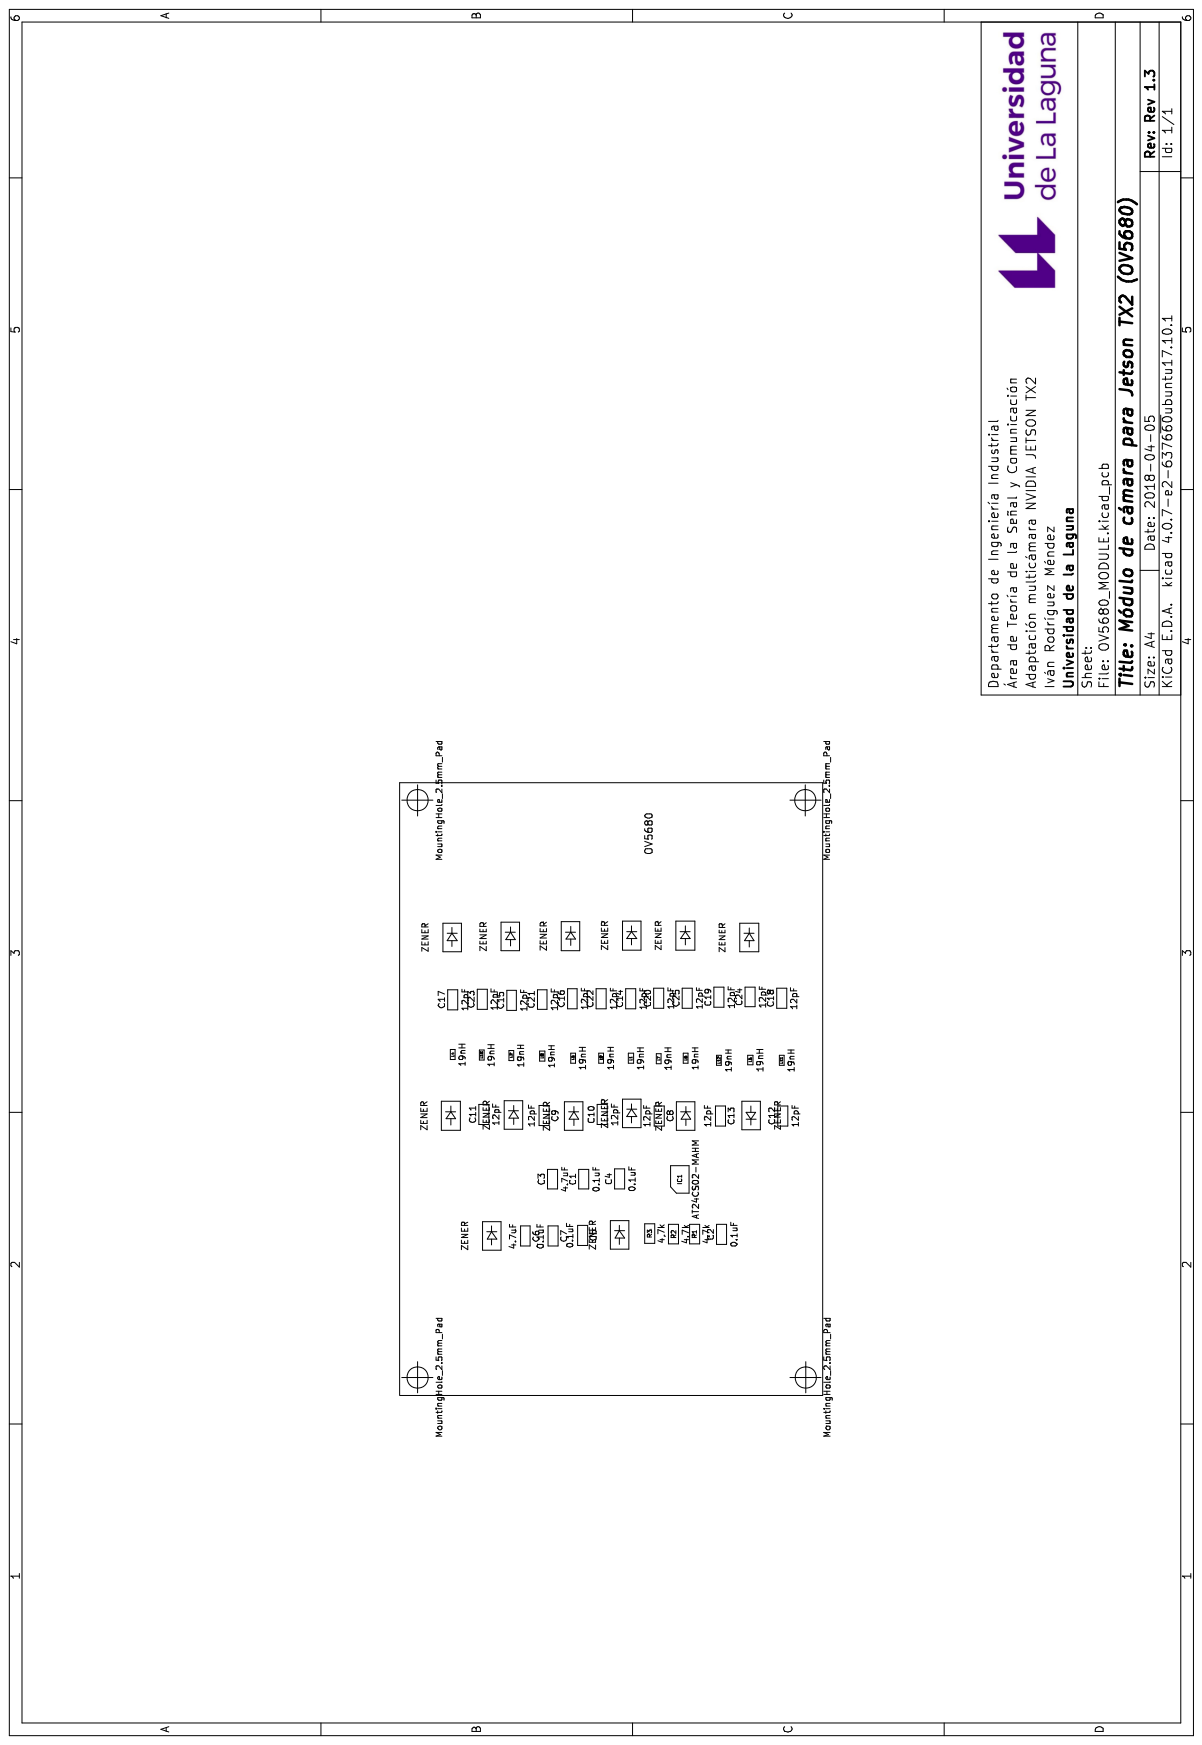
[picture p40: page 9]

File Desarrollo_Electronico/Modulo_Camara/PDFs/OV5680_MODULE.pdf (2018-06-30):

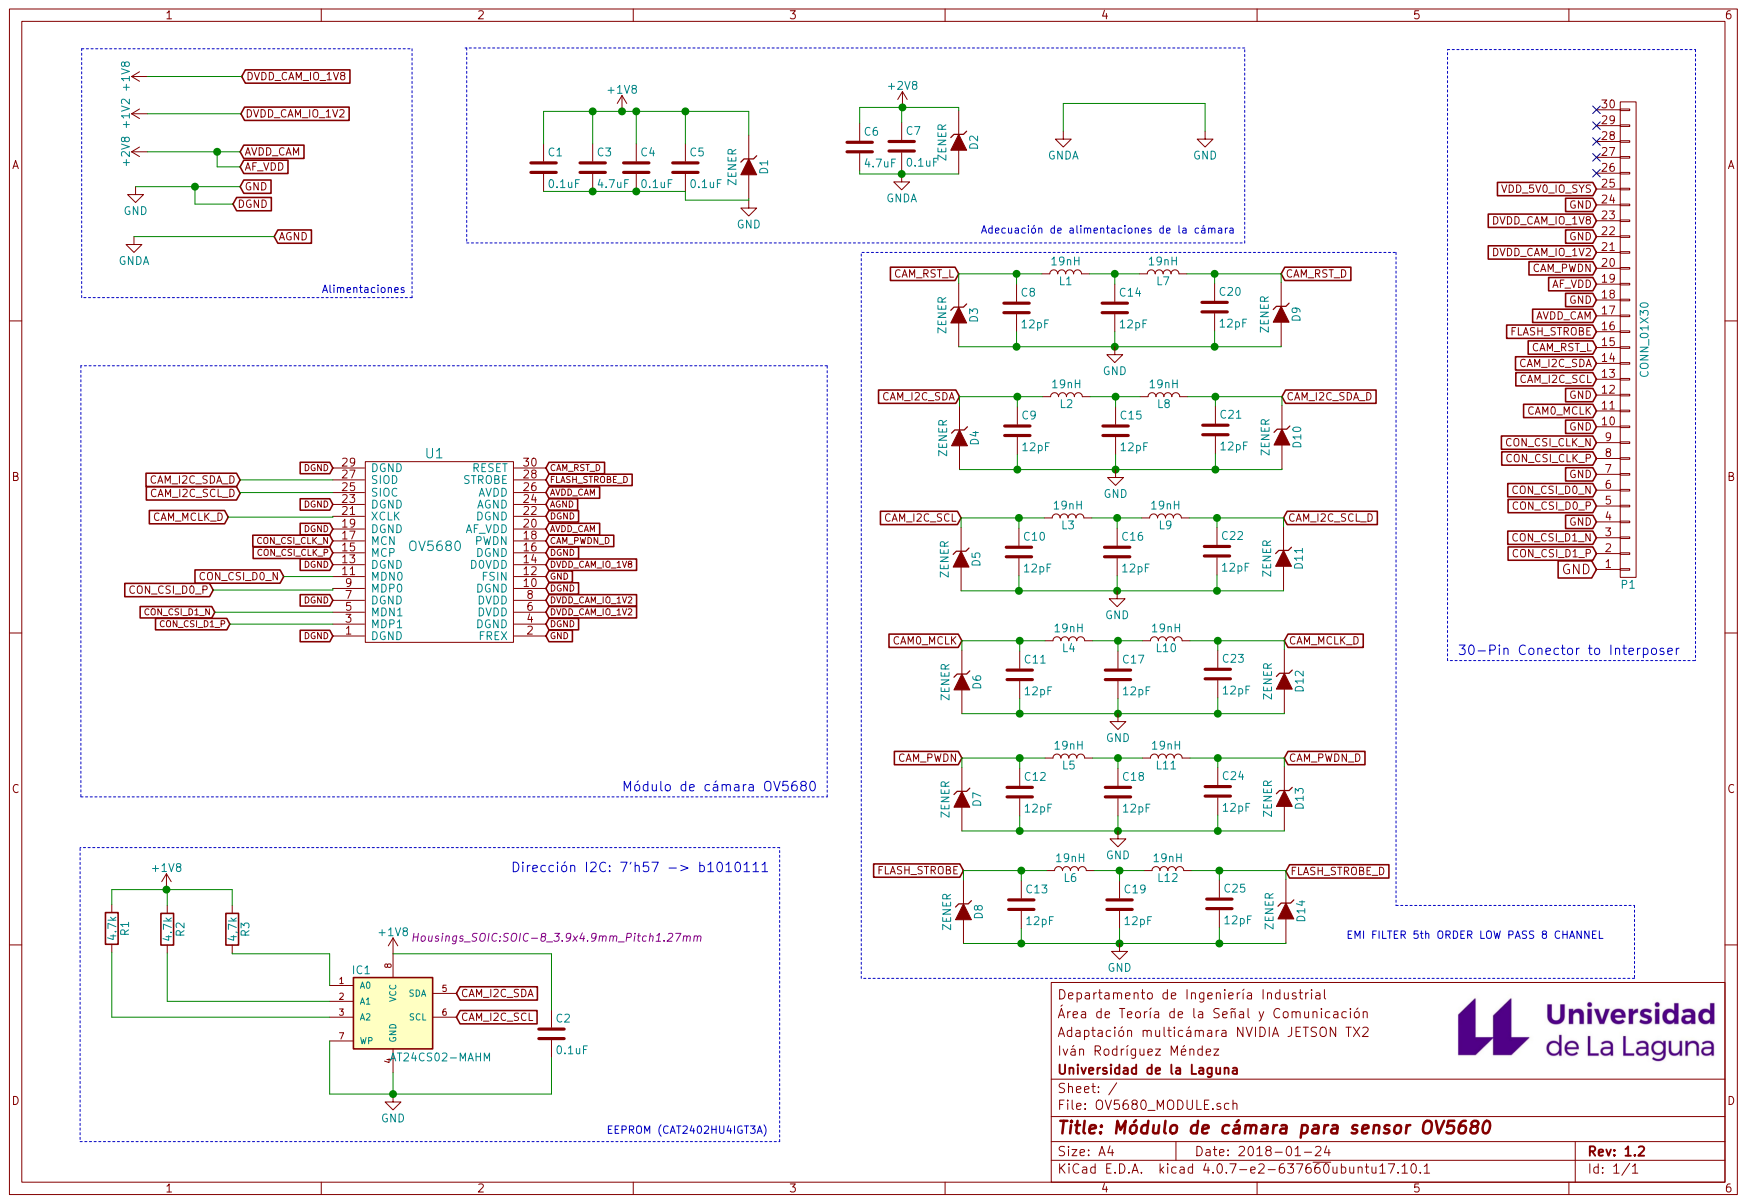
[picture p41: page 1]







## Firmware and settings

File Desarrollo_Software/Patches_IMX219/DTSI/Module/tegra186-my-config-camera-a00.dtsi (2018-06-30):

#include "dt-bindings/clock/tegra186-clock.h"
#include <dt-bindings/pinctrl/pinctrl-tegra.h>
#include <dt-bindings/gpio/tegra186-gpio.h>

#define CAM0_RST_L  TEGRA_MAIN_GPIO(R, 0)
#define CAM1_RST_L  TEGRA_MAIN_GPIO(N, 2)
#define CAM2_RST_L  TEGRA_MAIN_GPIO(R, 5)

#define CAM_0_MUX		TEGRA_AON_GPIO(V, 5)	//GPIO 0 on control UAV
#define CAM_1_MUX		TEGRA_MAIN_GPIO(X, 6)	//GPIO 1 on control UAV

/ {
	/* set camera gpio direction to output */
	gpio@2200000 {
		camera-control-output-low {
			status = "okay";
			gpio-hog;
			output-low;
			gpios = < CAM0_RST_L 0
				        CAM1_RST_L 0
                CAM2_RST_L 0
								CAM_1_MUX	 0>;
			label = "cam0-rst",
				      "cam1-rst",
              "cam2-rst",
							"cam-mux1";
		};
	};
	gpio@c2f0000 {
		aon-camera-control-output-low {
			status = "okay";
			gpio-hog;
			output-low;
			gpios = < CAM_0_MUX 0>;
			label = "cam-mux0";
		};
	};
};

/ {
  host1x {
		vi@15700000 {
      num-channels = <3>;
      ports {
        #address-cells = <1>;
        #size-cells = <0>;
        vi_port0: port@0 {
          status = "okay";
          reg = <0>;
          vi_in0: endpoint {
            status = "okay";
            csi-port = <0>;
            bus-width = <2>;
            remote-endpoint = <&imx219_csi_out0>;
          };
        };
        vi_port1: port@1 {
          status = "okay";
          reg = <1>;
          vi_in1: endpoint {
            status = "okay";
            csi-port = <2>;
            bus-width = <2>;
            remote-endpoint = <&imx219_csi_out1>;
          };
        };
        vi_port2: port@2 {
          status = "okay";
          reg = <2>;
          vi_in2: endpoint {
            status = "okay";
            csi-port = <4>;
            bus-width = <2>;
            remote-endpoint = <&imx219_csi_out2>;
          };
        };
    	};
		};

		nvcsi@150c0000 {
      status = "okay";
      num-channels = <3>;
      #address-cells = <1>;
      #size-cells = <0>;
			channel@0 {
        reg = <0>;
				status = "okay";
        ports {
          #address-cells = <1>;
          #size-cells = <0>;
					port@0 {
            status = "okay";
            reg = <0>;
            imx219_csi_in0: endpoint@0 {
            	status = "okay";
              csi-port = <0>;
              bus-width = <2>;
              remote-endpoint = <&imx219_phy_out0>;
            };
          };
					port@1 {
            status = "okay";
            reg = <1>;
            imx219_csi_out0: endpoint@1 {
            	status = "okay";
              remote-endpoint = <&vi_in0>;
            };
          };
        };
      };
			channel@1 {
        reg = <1>;
				status = "okay";
        ports {
          #address-cells = <1>;
          #size-cells = <0>;
					port@0 {
						status = "okay";
            reg = <0>;
            imx219_csi_in1: endpoint@2 {
						  status = "okay";
              csi-port = <2>;
              bus-width = <2>;
              remote-endpoint = <&imx219_phy_out1>;
            };
          };
					port@1 {
						status = "okay";
            reg = <1>;
            imx219_csi_out1: endpoint@3 {
						  status = "okay";
              remote-endpoint = <&vi_in1>;
            };
          };
        };
      };
			channel@2 {
        reg = <2>;
				status = "okay";
        ports {
          #address-cells = <1>;
          #size-cells = <0>;
					port@0 {
				    status = "okay";
            reg = <0>;
            imx219_csi_in2: endpoint@4 {
				      status = "okay";
              csi-port = <4>;
              bus-width = <2>;
              remote-endpoint = <&imx219_phy_out2>;
            };
          };
					port@1 {
				    status = "okay";
            reg = <1>;
            imx219_csi_out2: endpoint@5 {
              remote-endpoint = <&vi_in2>;
				      status = "okay";
            };
          };
        };
      };
    };
		//Make seperate module
      i2c@c240000 {
        #address-cells = <1>;
        #size-cells = <0>;
        reg = <0>;

        imx219_a@10 {
  		    #address-cells = <1>;
          #size-cells = <0>;

          //ADDED
          clocks = <&tegra_car TEGRA186_CLK_EXTPERIPH1>;
          clock-names = "extperiph1";
          mclk = "extperiph1";
          reset-gpios = <&tegra_main_gpio CAM0_RST_L GPIO_ACTIVE_LOW>;
          //reset-gpios = <&tegra_main_gpio CAM0_RST_L GPIO_ACTIVE_HIGH>;
          //vana-supply = <&en_vdd_cam_hv_2v8>;
          //vana-supply = <&en_vdd_cam_hv_2v8>;
          //vdig-supply = <&en_vdd_sys>;
          //dovdd-supply = <&en_vdd_cam>;
          //END

          devnode = "video0";
          compatible = "nvidia,imx219";
          reg = <0x10>;

          physical_w = "5.095";
          physical_h = "4.930";

          sensor_model ="imx219";
          //dovdd-supply = <&en_vdd_cam>;
          //avdd-reg = "vana";
          //dvdd-reg = "vdig";
          //iovdd-reg = "dovdd";
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

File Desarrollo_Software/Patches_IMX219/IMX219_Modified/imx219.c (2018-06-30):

/*
 * imx219.c - imx219 sensor driver
 *
 * Copyright (c) 2015-2016, NVIDIA CORPORATION.  All rights reserved.
 *
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
 * You should have received a copy of the GNU General Public License
 * along with this program.  If not, see <http://www.gnu.org/licenses/>.
 */

#include <dt-bindings/gpio/tegra-gpio.h>
#include <linux/slab.h>
#include <linux/uaccess.h>
#include <linux/gpio.h>
#include <linux/module.h>

#include <linux/seq_file.h>
#include <linux/of.h>
#include <linux/of_device.h>
#include <linux/of_gpio.h>

#include <media/camera_common.h>
#include <media/soc_camera.h>
#include <media/imx219.h>

#include "imx219_mode_tbls.h"

#define IMX219_MAX_COARSE_DIFF          4

#define IMX219_GAIN_SHIFT               (8)
#define IMX219_MIN_GAIN									(1 << IMX219_GAIN_SHIFT)
#define IMX219_MAX_GAIN									(16 << IMX219_GAIN_SHIFT)

#define IMX219_MIN_FRAME_LENGTH         (0x0)
#define IMX219_MAX_FRAME_LENGTH         (0x7FFF)
#define IMX219_MIN_EXPOSURE_COARSE      (0x0001)
#define IMX219_MAX_EXPOSURE_COARSE  \
  (IMX219_MAX_FRAME_LENGTH-IMX219_MAX_COARSE_DIFF)

#define IMX219_DEFAULT_GAIN             (IMX219_MIN_GAIN)
#define IMX219_DEFAULT_FRAME_LENGTH     (1766)
#define IMX219_DEFAULT_EXPOSURE_COARSE  \
  (IMX219_DEFAULT_FRAME_LENGTH-IMX219_MAX_COARSE_DIFF)

#define IMX219_DEFAULT_MODE IMX219_MODE_1920X1080
#define IMX219_DEFAULT_WIDTH        1920
#define IMX219_DEFAULT_HEIGHT       1080
#define IMX219_DEFAULT_DATAFMT      MEDIA_BUS_FMT_SRGGB10_1X10
#define IMX219_DEFAULT_CLK_FREQ     24000000

struct imx219 {
  struct camera_common_power_rail power;
  int       num_ctrls;
  struct v4l2_ctrl_handler  ctrl_handler;
  struct i2c_client   *i2c_client;
  struct v4l2_subdev    *subdev;
  struct media_pad    pad;
  struct regmap     *regmap;
  struct camera_common_data *s_data;
  struct camera_common_pdata  *pdata;
  struct v4l2_ctrl    *ctrls[];
};

static const struct regmap_config sensor_regmap_config = {
  .reg_bits = 16,
  .val_bits = 8,
  .cache_type = REGCACHE_RBTREE,
};

static int imx219_g_volatile_ctrl(struct v4l2_ctrl *ctrl);
static int imx219_s_ctrl(struct v4l2_ctrl *ctrl);

static const struct v4l2_ctrl_ops imx219_ctrl_ops = {
  .g_volatile_ctrl  = imx219_g_volatile_ctrl,
  .s_ctrl           = imx219_s_ctrl,
};

static struct v4l2_ctrl_config ctrl_config_list[] = {
/* Do not change the name field for the controls! */
  {
    .ops = &imx219_ctrl_ops,
    .id = V4L2_CID_GAIN,
    .name = "Gain",
    .type = V4L2_CTRL_TYPE_INTEGER,
    .flags = V4L2_CTRL_FLAG_SLIDER,
    .min = IMX219_MIN_GAIN,
    .max = IMX219_MAX_GAIN,
    .def = IMX219_DEFAULT_GAIN,
    .step = 1,
  },
  {
    .ops = &imx219_ctrl_ops,
    .id = V4L2_CID_FRAME_LENGTH,
    .name = "Frame Length",
    .type = V4L2_CTRL_TYPE_INTEGER,
    .flags = V4L2_CTRL_FLAG_SLIDER,
    .min = IMX219_MIN_FRAME_LENGTH,
    .max = IMX219_MAX_FRAME_LENGTH,
    .def = IMX219_DEFAULT_FRAME_LENGTH,
    .step = 1,
  },
  {
    .ops = &imx219_ctrl_ops,
    .id = V4L2_CID_COARSE_TIME,
    .name = "Coarse Time",
    .type = V4L2_CTRL_TYPE_INTEGER,
    .flags = V4L2_CTRL_FLAG_SLIDER,
    .min = IMX219_MIN_EXPOSURE_COARSE,
    .max = IMX219_MAX_EXPOSURE_COARSE,
    .def = IMX219_DEFAULT_EXPOSURE_COARSE,
    .step = 1,
  },
  {
    .ops = &imx219_ctrl_ops,
    .id = V4L2_CID_GROUP_HOLD,
    .name = "Group Hold",
    .type = V4L2_CTRL_TYPE_INTEGER_MENU,
    .min = 0,
    .max = ARRAY_SIZE(switch_ctrl_qmenu) - 1,
    .menu_skip_mask = 0,
    .def = 0,
    .qmenu_int = switch_ctrl_qmenu,
  },
  {
    .ops = &imx219_ctrl_ops,
    .id = V4L2_CID_HDR_EN,
    .name = "HDR enable",
    .type = V4L2_CTRL_TYPE_INTEGER_MENU,
    .min = 0,
    .max = ARRAY_SIZE(switch_ctrl_qmenu) - 1,
    .menu_skip_mask = 0,
    .def = 0,
    .qmenu_int = switch_ctrl_qmenu,
  },
  {
    .ops = &imx219_ctrl_ops,
    .id = V4L2_CID_FUSE_ID,
    .name = "Fuse ID",
    .type = V4L2_CTRL_TYPE_STRING,
    .flags = V4L2_CTRL_FLAG_READ_ONLY,
    .min = 0,
    .max = IMX219_FUSE_ID_STR_SIZE,
    .step = 2,
  },
};

static inline void imx219_get_frame_length_regs(struct reg_8 *regs, u16 frame_length)
{
  regs->addr = IMX219_FRAME_LENGTH_ADDR_MSB;
  regs->val = (frame_length >> 8) & 0xff;
  (regs + 1)->addr = IMX219_FRAME_LENGTH_ADDR_LSB;
  (regs + 1)->val = (frame_length) & 0xff;
}

static inline void imx219_get_coarse_time_regs(struct reg_8 *regs, u16 coarse_time)
{
  regs->addr = IMX219_COARSE_TIME_ADDR_MSB;
  regs->val = (coarse_time >> 8) & 0xff;
  (regs + 1)->addr = IMX219_COARSE_TIME_ADDR_LSB;
  (regs + 1)->val = (coarse_time) & 0xff;
}

static inline void imx219_get_gain_reg(struct reg_8 *regs, u8 gain)
{
  regs->addr = IMX219_GAIN_ADDR;
  regs->val = gain & 0xff;
}

static int test_mode;
module_param(test_mode, int, 0644);

static inline int imx219_read_reg(struct camera_common_data *s_data, u16 addr, u8 *val)
{
  struct imx219 *priv = (struct imx219 *)s_data->priv;
  return regmap_read(priv->regmap, addr, (unsigned int *) val);
}

static int imx219_write_reg(struct camera_common_data *s_data, u16 addr, u8 val)
{
  int err;
  struct imx219 *priv = (struct imx219 *)s_data->priv;

  err = regmap_write(priv->regmap, addr, val);
  if (err)
    pr_err("%s:i2c write failed, %x = %x\n",
      __func__, addr, val);

  return err;
}

static int imx219_write_table(struct imx219 *priv, const struct reg_8 table[])
{
  return regmap_util_write_table_8(priv->regmap,
           table,
           NULL, 0,
           IMX219_TABLE_WAIT_MS,
           IMX219_TABLE_END);
}

static void imx219_mclk_disable(struct camera_common_power_rail *pw)
{
  clk_disable_unprepare(pw->mclk);
}

static void imx219_mclk_enable(struct camera_common_power_rail *pw)
{
  clk_set_rate(pw->mclk, IMX219_DEFAULT_CLK_FREQ);
  clk_prepare_enable(pw->mclk);
}

static int imx219_power_on(struct camera_common_data *s_data)
{
  //int err = 0;
  struct imx219 *priv = (struct imx219 *)s_data->priv;
  struct camera_common_power_rail *pw = &priv->power;

  dev_info(&priv->i2c_client->dev, "%s: power on\n", __func__);

  if (gpio_cansleep(pw->reset_gpio))
    gpio_set_value_cansleep(pw->reset_gpio, 0);
  else
    gpio_set_value(pw->reset_gpio, 0);
  usleep_range(10, 20);

/*
  if (pw->avdd)
    err = regulator_enable(pw->avdd);
  if (err)
    goto imx219_avdd_fail;

  if (pw->iovdd)
    err = regulator_enable(pw->iovdd);
  if (err)
    goto imx219_iovdd_fail;

  if (pw->dvdd)
    err = regulator_enable(pw->dvdd);
  if (err)
    goto imx219_dvdd_fail;
*/

  //usleep_range(1, 2);
  usleep_range(10, 20);
  if (gpio_cansleep(pw->reset_gpio))
    gpio_set_value_cansleep(pw->reset_gpio, 1);
  else
    gpio_set_value(pw->reset_gpio, 1);

  //usleep_range(1, 2);
  usleep_range(10, 20);
  imx219_mclk_enable(pw);

  /* Need to wait for t4 + t5 + t9 time as per the data sheet */
  /* t4 - 200us, t5 - 6ms, t9 - 1.2ms */
  usleep_range(7400, 7410);

  pw->state = SWITCH_ON;
  return 0;

/*
imx219_dvdd_fail:
  regulator_disable(pw->iovdd);

imx219_iovdd_fail:
  regulator_disable(pw->avdd);
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

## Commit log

2018-06-30 Actualizamos el README
2018-06-30 Actualizamos la imagen del README
2018-06-30 Añadimos otra imagen de cabecera
2018-06-30 Añadimos el desarrollo mecánico y electrónico
    [A3_Landscape.dxf, A4_Landscape.dxf, Ajustador_V1.fcstd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]
2018-06-30 Añadimos todo el código desarrollado
2018-06-30 modificamos el README para añadir los resultados
2018-06-30 Modificamos la resolución de las imágenes de los resultados
2018-06-30 Añadimos las imágenes de las placas en 3D
2018-06-30 Añadimos el Readme para el desarrollo electrónico
2018-07-01 añadimos la redacción del trabajo
2018-07-03 Añadimos imágenes del array y el README de la sección de desarrollo mecánico
2018-07-03 Añadimos el README de la sección de software
2026-09-27 docs: add engineering case study
2026-09-27 docs: present TFM as engineering case study

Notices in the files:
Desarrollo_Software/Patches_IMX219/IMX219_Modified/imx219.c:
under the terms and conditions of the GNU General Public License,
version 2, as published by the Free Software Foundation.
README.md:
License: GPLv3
